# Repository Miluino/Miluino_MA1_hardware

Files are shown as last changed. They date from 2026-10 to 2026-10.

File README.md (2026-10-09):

# MDR32 Miluino

> [!IMPORTANT]
> AI-агенты перед анализом или изменением этого репозитория обязаны прочитать [общие правила работы AI-агентов](https://github.com/Miluino/dev-guidelines/blob/master/ai-agents.md), затем указанные ниже документы, относящиеся к текущей задаче. Полный рекурсивный анализ репозитория без необходимости не выполняется.

Проект новой ревизии отладочной платы на микроконтроллере `К1986ВЕ92FI`. Плата перерабатывается практически заново, поскольку исходная Miluino содержит конфликты выводов и другие схемотехнические ограничения.

Цель проекта — получить плату, которая:

- имеет геометрию разъёмов Arduino UNO и STMorpho; штатные шилды разрабатываются для Miluino, а совместимость готовых шилдов требует проверки распиновки, напряжений и направления питания пользователем;
- повторяет механическую карту STM32 Morpho платы `NUCLEO-F103RB`;
- предоставляет доступ к дополнительным функциям К1986ВЕ92FI через RAW-контакты;
- имеет однозначную коммутацию конфликтующих функций;
- содержит встроенный DAP-программатор/отладчик, VCP, USB и корректную систему питания.

## Техническая документация

Описание актуальной проектной схемы для технических специалистов разбито по узлам:

1. [Общее описание платы](docs/Техническая%20документация/01_Общее_описание_платы.md) — назначение, состав, интерфейсы и основные режимы.
2. [Питание платы и внешних устройств](docs/Техническая%20документация/02_Питание_и_внешние_выходы.md) — источники, T-селектор, защищённые выходы, токовые бюджеты и ограничения.
3. [К1986ВЕ92FI: распиновка и программирование](docs/Техническая%20документация/03_К1986_распиновка_и_программирование.md) — все выводы, Arduino, STMorpho, переключатели, USB-C и способы программирования.
4. [STM32F103CBU6: распиновка программатора](docs/Техническая%20документация/04_Программатор_распиновка.md) — все выводы, USB-C, отладочные разъёмы и служебные интерфейсы.

## С чего начать в новом чате

1. Прочитать этот README.
2. Для работы с выводами и текущим сигнальным листом обязательно перечитать [`docs/MDR32_MILUINO_pin_mapping.md`](docs/MDR32_MILUINO_pin_mapping.md).
3. Для работы с DAP прочитать релевантные разделы [`docs/CMSIS_DAP_rework.md`](docs/CMSIS_DAP_rework.md) и [`docs/CMSIS_DAP_power_reset_questions.md`](docs/CMSIS_DAP_power_reset_questions.md).
4. [`docs/Первоначальный промт.md`](docs/Первоначальный%20промт.md) использовать только как исторический контекст — повторно выполнять его не нужно.
5. Перед изменением любого рабочего документа перечитать его с диска: структура таблиц могла быть вручную изменена в ходе разработки.

При противоречии источников использовать следующий приоритет:

1. актуальная принципиальная схема;
2. `docs/MDR32_MILUINO_pin_mapping.md`;
3. этот README;
4. `docs/PROJECT_CONTEXT.md` и более ранние документы;
5. история обсуждений и первоначальный промт.

`docs/PROJECT_CONTEXT.md` содержит расширенный исторический контекст, но некоторые его формулировки о MODE, JTAG и AREF уже устарели.

## Текущая стадия

| Часть проекта | Оценочная готовность | Состояние |
|---|---:|---|
| Архитектура сигналов и распиновка | 85–90% | Основные назначения и конфликты проработаны |
| Сигнальный лист К1986ВЕ92FI | 80–85% | Реализован, требуется завершить номиналы и служебную обвязку |
| Полная электрическая схема | 45–55% | Не завершены питание, DAP, USB и итоговая проверка |

Распределение ограниченного количества выводов в основном закончено. Проект пока не готов к окончательной разводке PCB: сначала необходимо спроектировать питание и заземление, затем закончить DAP и остальные интерфейсные листы.

## Зафиксированные решения сигнального листа

### Arduino и Morpho

- Опорная карта STMorpho — `NUCLEO-F103RB`, Figure 12 на странице 28 UM1724.
- Обозначения Arduino I2C: `D18/SDA` и `D19/SCL`.
- Единственная аппаратная шина I2C К1986 использует `PC1/SDA1` и `PC0/SCL1`.
- D18/D19 постоянно подключены к PC1/PC0; A4/A5 переключаются между ADC и дублированием этой I2C-шины.
- `IOREF=3,3 В`. Наличие +5 В на Arduino-разъёме не означает 5-вольтовые логические уровни GPIO.
- `BOOT0` Nucleo оставлен NC.
- `MODE[2:0]` полностью изолированы от Morpho, BOOT0 и внешних GPIO и задаются только локальными переключателями.

### UART, VCP и отладка

- Arduino D1/D0 постоянно подключены к `PB5/UART1_TXD` и `PB6/UART1_RXD`.
- VCP использует UART2 на PD0/PD1 через нормально не установленные R1105/R1106.
- В штатном состоянии PD0/PD1 подключены к Morpho и JTAG_B через R1005/R1006.
- JTAG реализован групповым джамперным `JTAG_Channel_Selector` на пять сигналов: общая JTAG-шина выбирает JTAG_A на PB0–PB4 либо JTAG_B на PD0–PD4.
- Одновременное соединение одного JTAG-сигнала с каналами A и B запрещено.
- XP7 используется для SWD внешней target с логическими уровнями 3,3 В; его контакт 1 называется `EXT_VTREF` и принимает опорное напряжение от внешней платы.
- Питание внешней target через XP7 не передаётся. Для намеренной подачи питания от программатора предусматриваются отдельные контакты `+5V_DAP_OUT` и `+3V3_DAP_OUT`; общий контакт GND берётся с расположенного рядом `SPARE JMP`. Оба выхода используют общий токовый ключ `TPS2553-1` с целевым суммарным пределом около 300 мА.
- Встроенный DAP реализует только SWD: PB13 формирует SWCLK, PB14 используется как единая двунаправленная линия SWDIO, а PB12 управляет внешним NMOS линии nRESET.
- nRESET встроенного DAP формируется внешним NMOS 2N7002; PB12 подключён к gate через 1 кОм, gate подтянут к GND резистором 10 кОм.
- Выбранный XP8 сигнал VTref контролируется NMOS-детектором с активным низким выходом `nDAP_VTREF_PRESENT` на PA0: в gate включён последовательный резистор 1 кОм, gate подтянут к source резистором 10 кОм, drain подтянут к `+3V3_DAP` резистором 10 кОм.
- Детектор VTref подтверждает только наличие напряжения и не является проверкой диапазона 3,0...3,6 В; подключать разрешается только target с логикой 3,3 В.
- Логгер DAP использует PA9/USART1_TX как `DAP_LOG_TX` и PA10/USART1_RX как `DAP_LOG_RX`.
- Первичная прошивка, восстановление и отладка STM32F103 выполняются внешним SWD-адаптером через установленный XP5 1x5 с шагом 2,54 мм: `+3V3_DAP`, SWDIO, GND, SWCLK и NRST. Контакт `+3V3_DAP` используется как VTref, а не как вход питания.
- XP5 UART и XP9 BOOT0 удаляются; BOOT0 и PB2/BOOT1 постоянно подтягиваются к GND через 10 кОм. Отдельная кнопка RESET DAP не устанавливается, перезапуск и смена прошивки выполняются с полным отключением питания всей платы.
- Локальная линия `TARGET_nRESET` имеет единственную подтяжку к `+3V3_TGT`; кнопка, встроенный DAP, внешний DAP и shield могут только притягивать её к GND. Активный высокий уровень и подтяжка к 5 В не предусматриваются; C1 номиналом 100 нФ, X7R устанавливается между `TARGET_nRESET` и GND для фильтрации помех и дребезга кнопки.

### Тактирование и служебные сигналы

- Штатный HSE: `DAP_MCO -> R109 22 Ом -> DAP_MCO_Line -> R1003 0 Ом -> OSC_IN`; отдельный `R_EN_DAP` не устанавливается.
- Локальный кварц HSE подключается через R1103/R1213, внешний генератор через R1203; сервисный OSC_OUT выведен через R1113.
- PE6/PE7 штатно выведены на Morpho через R1007/R1008; локальный LSE выбирается через R1107/R1108.
- WAKEUP имеет постоянную подтяжку к VCC и подключается к Morpho через нормально не установленный R13. Внешнее устройство должно использовать open-drain или open-collector.
- STANDBY выводится на Morpho через последовательный резистор и используется внешней платой только как входной сигнал.
- Пользовательская кнопка использует PB9 и отключается от него резистором R9.
- Четыре active-high LED используют PA1, PA2, PA3 и PA5 через индивидуальные токоограничивающие резисторы.

### USB целевого К1986

- Контроллер `MDR_USB` поддерживает программно выбираемые режимы Device и Host по USB 1.0, скорости Full Speed 12 Мбит/с и Low Speed 1,5 Мбит/с.
- Возможность Host/Device внутри К1986 не делает разъём автоматически двухролевым USB-C: выводов CC и встроенного управления VBUS у МК нет.
- USB-C target работает только как постоянный Device/UFP/Sink: CC1 и CC2 имеют отдельные `Rd=5,1 кОм, 1 %` к GND, а VBUS используется только как вход питания. Режимы Host/DFP/Source и dual-role через этот разъём не поддерживаются.
- VBUS USB-C target поступает непосредственно на свой вход T-селектора: дополнительный eFuse или ограничитель тока в этой ветви не устанавливается. Потребление через этот разъём должно соответствовать разрешённому USB-хостом току; заявление тока в дескрипторе DAP относится к другому USB-C. Экраны обоих USB-C соединены с GND напрямую.
- Для DP/DN в любом варианте нужны низкоёмкостная ESD-защита, места под последовательные согласующие резисторы и корректная дифференциальная трассировка.
- Следует учесть errata 0033: при наличии Ucc и отсутствии внутреннего питания USB, в том числе до его запуска и в STANDBY, на DP и DN могут одновременно включаться внутренние подтяжки 1,5 кОм к Ucc.

### Питание target от VIN

- Для входа VIN принят рабочий диапазон 8...18 В с целевым номиналом 12 В.
- Стабильные `+5V_IN_Line` формирует синхронный преобразователь `LMR51410XDBVR`, работающий на частоте 400 кГц в режиме PFM. Приняты дроссель 33 мкГн, входные конденсаторы 4,7 мкФ + 100 нФ, bootstrap-конденсатор 100 нФ, выходной конденсатор 22 мкФ и делитель обратной связи 118 кОм / 22,1 кОм.
- Вывод EN `LMR51410XDBVR` подключается непосредственно к VIN. Внешний диод Шоттки, дополнительный bulk-конденсатор и резисторы минимальной нагрузки не устанавливаются; полезная нагрузка target ограничена принятыми 300 мА.
- Общий выход T-селектора называется `+5V_TGT`; от него `TLV76133DCYR` с входным конденсатором 1 мкФ X7R и выходным 4,7 мкФ X7R формирует `+3V3_TGT` для К1986 и IOREF.
- От `+5V_TGT` второй `TPS2553-1` питает защищённую ветвь Output Power для внешнего питания: `+5V_Out_Line` идёт на контакт +5V, а отдельный `TLV76133DCYR` после ключа формирует `+3V3_Out_Line` для контакта +3V3. Эти же защищённые шины выведены на STMorpho CN7.11/CN7.18 (+5V) и CN7.9/CN7.16 (+3V3); ток нагрузок Arduino и этих контактов Morpho учитывается в одном пределе второго TPS2553-1; R28=100 кОм; типовой порог ограничения около 266 мА, расчётный верхний порог при допуске резистора 1 % около 306 мА. Входом `EN` управляет только PB10 К1986 через штатно установленный R1004=0 Ом и сеть `TGT_OUTPUT_PWR_EN` при любом выбранном источнике target; R27=10 кОм удерживает `EN` на GND до настройки GPIO. Прошивка не включает защищённые выходы автоматически после инициализации: PB10 переводится в активное состояние только по явной команде. Ветвь к Morpho CN10.2 через R1104=0 Ом штатно разомкнута. `DAP_TARGET_PWR_EN` к этому ключу не подключается.
- Прямые контакты STMorpho CN7.5/CN7.12/CN7.33 (`+3V3_TGT`) и CN7.6/CN7.26/CN10.8 (`+5V_TGT`) допускаются только для высокоомного контроля напряжения при необходимости. Питать от них шилд или другую внешнюю нагрузку и подавать через них внешнее напряжение строго запрещено. IOREF на CN7.12 показывает уровень питания К1986 независимо от состояния PB10; CN7.26 позволяет контролировать `+5V_TGT` при выключенных защищённых выходах. Ограничение тока и запрет обратной подачи на прямых контактах не обеспечены аппаратно.
- При питании К1986 от USB-C DAP для расчёта бюджета VBUS зарезервировано по 100 мА для К1986 и STM32F103 с запасом относительно данных производителей. Суммарный ток внешних нагрузок выходов DAP и защищённой ветви Output Power (Arduino/Morpho) ограничен правилом эксплуатации 300 мА: 100 + 100 + 300 = 500 мА, заявленные для USB-C DAP. Любая нагрузка на прямых контактах Morpho тоже входит в этот внешний бюджет 300 мА, хотя второй TPS2553-1 её не ограничивает. Два TPS2553-1 ограничивают ток каждый в своей ветви и аппаратно не обеспечивают общий предел 300 мА; постоянная значительная нагрузка сразу на оба канала не является штатным сценарием. При питании К1986 от USB-C target или VIN бюджеты источников рассчитываются отдельно.
- `FAULT` ключа ветви Output Power имеет локальную светодиодную индикацию и подтяжку R26=100 кОм к `+5V_TGT`. Для опционального чтения К1986 сигнал подан на gate VT1=2N7002; source соединён с GND, drain подтянут R24=10 кОм к `+3V3_TGT` и через R25=1 кОм соединяется с PE3/CN10.10. R25 штатно не установлен (DNP), поэтому по умолчанию PE3 остаётся свободным GPIO. При установленном R25 высокий уровень PE3 означает аварию, низкий — отсутствие активного `FAULT`, но не подтверждает наличие выходного напряжения. Контакт CN10.10 в этой конфигурации нельзя использовать как независимый вход или выход шилда. `FAULT` ключа DAP остаётся только на локальном светодиоде и не подаётся на STM32F103 или К1986. Версия ключа `-1` защёлкивается при аварии; повторное включение требует переключения `EN` либо снятия питания. Автоматическое программное восстановление не предусматривается.
- Отдельный eFuse ветви VIN не устанавливается. Короткое замыкание на открытых контактах питания или во внешней проводке считается маловероятным принятым риском; встроенные ограничение тока и hiccup-защита `LMR51410XDBVR` являются только аварийной самозащитой микросхемы.
- Штатное питание платы осуществляется через USB-C DAP. Вход VIN не имеет отдельной защиты от переполюсовки, длительного перенапряжения и броска входного тока; внешний источник либо shield должен обеспечивать правильную полярность, стабилизированное напряжение 8...18 В, ограничение тока и необходимую входную защиту.

### AREF

Штатный R1009 соединяет Arduino AREF с `+3V3_TGT`; R1109 к `PD0/JB_TMS_Line` штатно не устанавливается. Внешняя опора АЦП через AREF в текущей сборке не поддерживается: для неё согласована цепь AREF → R1109 → `PD0/JB_TMS_Line` → R1005 → `ADC0_REF+` и уже предусмотренный в схеме R1206=0 Ом (DNP) от `ADC1_REF−` к GND; при внешней опоре Morpho CN10.34 должен оставаться свободным, JTAG_B — отключённым. Питание AUcc и связь AGND с GND проверяются по листу питания; подавать внешнее напряжение на AREF при установленном R1009 нельзя.

## Правило аннотации резисторов-перемычек

В Comment компонентов `.IntLib` записывается только номинал с множителем и десятичной запятой (например, `4,7u`, `22,1k`, `0`) либо модель; единицы, допуски, роль компонента и DNP указываются в Description. Для неутверждённого номинала или модели используется `TBD`. Description заполнен на трёх листах, включая символы `.SchLib`; их Comment и Designator требуют отдельной аннотации.

Для Designator R, C, HL и VT диапазон 1…99 отведён узлам К1986, 100…199 — узлам DAP. Порядок назначения следует листам 1–3 PDF; внутри листа элементы нумеруются сверху вниз по столбцам, затем слева направо. Одиночные резисторы, включая DNP, входят в диапазон своего узла.

- R1000…R1099 — штатные, нормально установленные резисторы;
- R1100…R1199 — первый альтернативный, нормально не установленный канал;
- R1200…R1299 — второй альтернативный, нормально не установленный канал;
- элементы с одинаковыми двумя последними цифрами образуют группу выбора;
- для двух штатно не установленных ветвей OSC_OUT используется пара R1113/R1213 без позиции R1013;
- в группе одновременно устанавливается только один канал;
- JTAG_A/JTAG_B выбирается джамперами и в эту систему резисторов не входит.
- Штатная комплектация и DNP-элементы пока задаются Description компонентов и таблицей конфигураций; отдельный вариант сборки Altium не создан. Перед выпуском ведомости комплектации DNP-позиции требуется отфильтровать вручную либо оформить вариант сборки.

Полная фактическая таблица R1000–R1213 и типовые конфигурации находятся в разделе 13 [`MDR32_MILUINO_pin_mapping.md`](docs/MDR32_MILUINO_pin_mapping.md).

## Что ещё предстоит спроектировать

- завершить проверку заземления и распределения Ucc/AUcc/AUcc1; BUcc штатно напрямую подключён к `+3V3_TGT`, отдельный резервный источник не предусматривается;
- подтвердить измерениями диапазон ограничения второго TPS2553-1 при R28=100 кОм; определить команду включения `TGT_OUTPUT_PWR_EN` в прошивке К1986 и проверить её поведение при разных источниках питания, сбросе и перегрузке. Автоматическое включение после инициализации не предусматривается;
- проверить для будущего режима внешней опоры уже предусмотренную цепь R1109+R1005/R1206 и допустимый диапазон опоры;
- локальную развязку всех выводов питания;
- окончательный номинал подтяжки `TARGET_nRESET`, ESD-защиту линии и необходимость внешнего супервизора питания target;
- выбрать конкретные диоды Шоттки защиты LDO `+3V3_DAP_OUT` и проверить ресурсы прошивки CMSIS-DAP v2 + CDC/VCP + SWO;
- подтвердить измерениями общий токовый предел, защиту от КЗ и обратного питания выходов `+5V_DAP_OUT` и `+3V3_DAP_OUT`;
- завершить номиналы и согласующие элементы USB-C целевого К1986 в принятой конфигурации Device/UFP/Sink; отдельная силовая защита VBUS не устанавливается;
- окончательные номиналы MODE, RESET, LED, кнопки, WAKEUP/STANDBY и кварцев;
- защиту внешних аналоговых и цифровых линий;
- завершить Comment/Designator символов `.SchLib`, утвердить оставленные `TBD` номиналы и исполнения, затем выполнить ERC, проверку нетлиста, BOM и посадочных мест.

## Документы проекта

| Файл | Назначение |
|---|---|
| [`docs/MDR32_MILUINO_pin_mapping.md`](docs/MDR32_MILUINO_pin_mapping.md) | Главная актуальная карта выводов, разъёмов и резисторов выбора |
| [`docs/CMSIS_DAP_rework.md`](docs/CMSIS_DAP_rework.md) | Архитектура встроенного CMSIS-DAP; часть решений ещё требует утверждения |
| [`docs/CMSIS_DAP_power_reset_questions.md`](docs/CMSIS_DAP_power_reset_questions.md) | Вопросы и критерии проверки питания, VTref и RESET |
| [`docs/STM32F103_DAP_pinout.md`](docs/STM32F103_DAP_pinout.md) | Распиновка DD2 и рекомендуемые подключения встроенного DAP |
| [`docs/future_changes.md`](docs/future_changes.md) | Согласованные изменения, ещё не внесённые в принципиальную схему |
| [`docs/PROJECT_CONTEXT.md`](docs/PROJECT_CONTEXT.md) | Расширенный, но частично устаревший контекст предыдущих обсуждений |
| [`docs/Первоначальный промт.md`](docs/Первоначальный%20промт.md) | Историческая постановка задачи, не инструкция к повторному выполнению |
| [`codex/datasheet_K1986VE92FI_pinout.md`](codex/datasheet_K1986VE92FI_pinout.md) | Индекс выводов и функций К1986ВЕ92FI |
| [`codex/datasheet_STM32_Nucleo64_UM1724.md`](codex/datasheet_STM32_Nucleo64_UM1724.md) | Индекс руководства Nucleo-64 |
| [`codex/datasheet_Arduino_UNO_R4_Minima.md`](codex/datasheet_Arduino_UNO_R4_Minima.md) | Индекс Arduino UNO R4 Minima |

Каталог `datasheets` содержит первичные PDF/DOCX. Файлы в `codex` являются только поисковыми индексами; критичные электрические параметры необходимо проверять по оригинальным документам.

## Ключевые ограничения

- GPIO платы работают с логическими уровнями 3,3 В; полная совместимость с произвольными 5-вольтовыми shields не заявляется.
- PD0–PD7 нельзя считать 5-вольт-совместимыми.
- Два активных выхода нельзя объединять одной дорожкой.
- RAW-контакт — дополнительная точка той же сети, а не независимый сигнал.
- Альтернативные резисторные каналы переключаются только на обесточенной плате.
- MODE считывается при включении питания; обычный RESET не применяет новое состояние MODE.
- Оба USB-C работают только как Device/UFP/Sink и имеют отдельные `Rd=5,1 кОм, 1 %` на CC1 и CC2; режимы Host/Source и dual-role через эти разъёмы не поддерживаются.
- В общей силовой части и цепи RESET локальной target остаются открытые вопросы; для будущей внешней опоры AREF согласована коммутация R1005/R1109/R1206; R1206 уже внесён в схему как DNP, а параметры режима требуют проверки. Согласованные аппаратные узлы встроенного DAP зафиксированы в профильных документах.
- `EXT_VTREF` является входом контроля питания внешней target и не должен использоваться как выход питания; для этого предназначены только отдельные контакты `+5V_DAP_OUT` и `+3V3_DAP_OUT`, а GND берётся с расположенного рядом `SPARE JMP`.

## Рекомендуемое первое сообщение в новом чате

```text
Прочитай README.md и актуальные рабочие документы, на которые он ссылается.
Первоначальный промт повторно не выполняй. Используй текущую принципиальную
схему и MDR32_MILUINO_pin_mapping.md как основные источники состояния проекта.
После этого продолжим обсуждение переработки Miluino с текущей стадии.
```

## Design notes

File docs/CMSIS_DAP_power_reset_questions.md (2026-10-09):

# Питание, VTref и RESET для CMSIS-DAP

## 1. Назначение и статус документа

Документ фиксирует согласованные решения по питанию, VTref и RESET новой ревизии MDR32 MILUINO, а также вопросы, которые необходимо закрыть до утверждения принципиальной схемы. Он заменяет исходный чек-лист: принятые решения изложены связно, а неутверждённые параметры перечислены отдельно.

Связанный документ: [CMSIS_DAP_rework.md](CMSIS_DAP_rework.md).

## 2. Неизменяемые исходные решения

Для текущей ревизии приняты следующие ограничения:

1. Встроенный DAP остаётся на STM32F103 и получает собственное питание от USB-C DAP.
2. DAP и локальный К1986ВЕ92FI рассматриваются как отдельные домены `+3V3_DAP` и `+3V3_TGT` с общей GND; гальваническая изоляция не предусматривается.
3. XP8/DAP_ROUTE одновременно переключает SWCLK, SWDIO, nRESET, VTref и SWO между `EXTERNAL / OFF / TARGET`.
4. XP7 не питает внешнюю target. Его контакт 1 `EXT_VTREF` используется только как вход опорного напряжения.
5. ARM Cortex Debug 10-pin подключён к локальной общей DBG-шине и получает VTref от локальной target.
6. nRESET локальной и внешней target не соединяются постоянно.
7. RESET встроенного STM32F103 и nRESET target являются разными цепями.
8. После изменения MODE[2:0] требуется полный цикл выключения и включения основного питания К1986ВЕ92FI; обычного RESET недостаточно.
9. Оба USB-разъёма новой ревизии выполняются в формате USB-C.
10. Встроенный DAP поддерживает только target с логическими уровнями 3,3 В; поддержка target с уровнями 1,8 В или 2,5 В не предусматривается.
11. Специальная аппаратная защита от подпитки выключенного домена через сигнальные линии не предусматривается. Связанный с этим риск принимается и относится к ограничениям эксплуатации платы.
12. Возможность питания внешней target от программатора сохраняется только через отдельные контакты `+5V_DAP_OUT` и `+3V3_DAP_OUT`, не связанные с силовой передачей через XP7; GND берётся с расположенного рядом `SPARE JMP`.
13. Встроенный DAP реализует только SWD: PB13 используется как SWCLK, PB14 — как единая двунаправленная линия SWDIO, PB12 управляет внешним NMOS линии nRESET.
14. Контроль наличия выбранного VTref выполняется согласованным NMOS-детектором с активным низким выходом; компаратор не устанавливается.
15. Ветвь управления nRESET target от встроенного DAP формируется внешним NMOS 2N7002 по схеме открытого стока; подтяжка остаётся на target-стороне.
16. STM32F103 программируется, восстанавливается и отлаживается внешним SWD-адаптером через установленный разъём XP5 1x5 с шагом 2,54 мм; XP5 UART и XP9 BOOT0 не используются.
17. Отдельная кнопка RESET DAP не устанавливается; его обычная перезагрузка и смена прошивки предусматривают полное отключение питания всей отладочной платы.
18. Между `TARGET_nRESET` и GND устанавливается C1 номиналом 100 нФ, X7R для фильтрации помех и дребезга кнопки.
19. Оба внешних выхода питания DAP образуют единый защищённый домен с общим ограничением тока; отдельные независимые токовые бюджеты для них не предусматриваются.
20. Специальная защита от обратного питания устанавливается только на пользовательских выходах `+5V_DAP_OUT` и `+3V3_DAP_OUT`. Остальные шины не предназначены для подачи внешнего напряжения и дополнительных обратных ключей не получают.

## 3. Согласованная архитектура питания

### 3.1. Источники и преобразование

Домен DAP питается только от собственного USB-C:

```text
USB_DAP_VBUS --+--> TLV76133DCYR --> +3V3_DAP
               |
               +--> TPS2553-1 --> +5V_DAP_OUT
               |                      |
               |                      +--> D1 Шоттки --> TLV76133DCYR --> +3V3_DAP_OUT
               |                                           ^              |
               |                                           +-- D2 Шоттки -+
               |
               +--> P-MOSFET --> +5V_DAP_USB --> DAP-вход T-селектора --> +5V_TGT --> +3V3_TGT --> К1986
```

Входом всех трёх трактов является номинальный VBUS 5 В USB-C DAP. Поддержка USB Power Delivery и подача на VBUS напряжений 9...20 В не предусматриваются. Внутренний домен `+3V3_DAP` не нагружается питанием внешней платы: отдельный LDO внешнего выхода получает питание от защищённой пятивольтовой ветви после `TPS2553-1`.

`TPS2553-1` задаёт общий токовый предел двух внешних выходов и отключает N-канальный силовой MOSFET при обратном напряжении. Для `R122=100 кОм, 1 %` типовой порог составляет около 266 мА; расчёт по формулам TI с учётом допуска резистора даёт ориентировочно 232...306 мА. Поэтому 300 мА — целевой уровень, а не гарантированный максимальный порог или гарантированно доступный ток нагрузки. При `VOUT > VIN` защита имеет конечное время срабатывания: порог компаратора составляет 95...190 мВ, отключение MOSFET занимает 3...7 мс, после чего версия `-1` остаётся защёлкнутой до переключения `EN` либо полного снятия питания. Поэтому узел блокирует продолжительное обратное питание USB VBUS, но не считается безынерционным ideal-diode.

На входе `TPS2553-1` устанавливается неполярный керамический конденсатор 1 мкФ, X7R, не менее 10 В. На выходе устанавливается неполярный керамический конденсатор 22 мкФ, X7R, не менее 10 В; его эффективная ёмкость при постоянном смещении 5 В должна быть не менее 10 мкФ. Предпочтителен корпус 1206 или крупнее либо параллельное включение двух конденсаторов 10 мкФ после проверки зависимости ёмкости от напряжения. Этот конденсатор служит накопительной ёмкостью для переходных процессов внешней нагрузки; полярный символ применяется только при фактическом выборе электролитического, танталового или полимерного компонента.

PA1 STM32F103 формирует активный высоким уровнем сигнал `DAP_TARGET_PWR_EN`. Сигнал напрямую подключается к `EN` микросхемы `TPS2553-1` внешних выходов и через резистор 1 кОм управляет gate отдельного NMOS 2N7002. Source 2N7002 соединяется с GND, а drain — с gate силового P-MOSFET ветви питания локальной target. Source P-MOSFET подключается к `USB_DAP_VBUS`, drain формирует `+5V_DAP_USB`, а gate подтягивается к source резистором 10 кОм. При `DAP_TARGET_PWR_EN=1` включаются оба независимых силовых тракта; при нуле или high-Z они выключены. Ток К1986 не проходит через `TPS2553-1` внешних выходов, поэтому авария этого ключа не должна выключать локальную target.

У gate NMOS установлен резистор 10 кОм к GND; PA1 подключён к gate через последовательный резистор 1 кОм. Поэтому PA1 и вход `EN` TPS2553-1 внешних выходов получают путь к GND через 1 кОм + 10 кОм, а отдельной прямой подтяжки 10 кОм на общей сети `DAP_TARGET_PWR_EN` в текущей схеме нет. После сброса PA1 остаётся высокоимпедансным входом, и эта цепь удерживает оба тракта выключенными. Прошивка сначала записывает ноль в выходной регистр PA1 и переводит его в push-pull output, а единицу устанавливает только после получения `SET_CONFIGURATION` для конфигурации USB с заявленным током 500 мА. При USB suspend, сбросе или деконфигурации шины, `SET_CONFIGURATION(0)` и потере VBUS сигнал должен быть сброшен в ноль. Выход `FAULT` этого ключа не подключён к STM32F103; программное обнаружение аварии и автоматические попытки повторного включения не предусматриваются.

Для питания локальной target предусмотрены три источника:

1. коммутируемый сигналом `DAP_TARGET_PWR_EN` VBUS USB-C DAP;
2. необработанный `USB_VBUS` отдельного USB-C target без дополнительного ограничителя тока на плате;
3. внешний источник, подключённый к VIN на Arduino/STMorpho.

Ветвь VIN перед селектором содержит `LMR51410XDBVR`, формирующий стабильные 5 В из входных 8...18 В. USB-C target подаёт свой VBUS на селектор без отдельного eFuse; допустимое потребление определяется USB-хостом и конфигурацией именно этого USB-устройства. Структура target имеет вид:

```text
USB-C DAP VBUS -- P-MOSFET ------------------+
                                              |
USB-C target USB_VBUS ------------------------+-- T-селектор -- +5V_TGT -- TLV76133DCYR -- +3V3_TGT -- К1986, IOREF, Morpho CN7.5/CN7.12/CN7.33
                                              |                    |
VIN ---------------- LMR51410XDBVR -----------+                    +-- Morpho CN7.6/CN7.26/CN10.8 (+5V; CN7.26 — контроль)
                                                                   |
                                                                   +-- второй TPS2553-1 -- +5V_Out_Line -- Arduino +5V, Morpho CN7.11/CN7.18
                                                                                         |
                                                                                         +-- TLV76133DCYR -- +3V3_Out_Line -- Arduino +3V3, Morpho CN7.9/CN7.16
```

Рабочие имена сетей для последующего согласования схемы:

- `USB_DAP_VBUS` и `USB_VBUS` — VBUS отдельных USB-C DAP и target;
- `+5V_DAP_USB` — коммутируемая P-MOSFET ветвь от `USB_DAP_VBUS`, разрешаемая сигналом `DAP_TARGET_PWR_EN`; `USB_VBUS` идёт от USB-C target на селектор напрямую;
- `+5V_IN_Line` — выход `LMR51410XDBVR` до T-селектора;
- `+5V_TGT` — общий выход T-селектора;
- `+3V3_TGT` — выход `TLV76133DCYR` локальной target;
- `+5V_Out_Line` и `+3V3_Out_Line` — выходы ветви Output Power после второго TPS2553-1, причём 3,3 В формируются отдельным LDO;
- `TGT_OUTPUT_PWR_EN` — активный высоким уровнем сигнал PB10 К1986 на `EN` второго TPS2553-1 ветви Output Power; при сбросе удерживается на GND резистором R27=10 кОм;
- `+3V3_DAP` — отдельное питание STM32F103;
- `+5V_DAP_OUT` — защищённая пятивольтовая ветвь внешнего питания после `TPS2553-1`;
- `+3V3_DAP_OUT` — выход отдельного LDO внешнего питания после `TPS2553-1`.

### 3.2. T-образный селектор источника

Источник target выбирается вручную одним стандартным джампером 2,54 мм на четырёхконтактной T-образной гребёнке. Центральный контакт подключён к `+5V_TGT`, три окружающих контакта — к `+5V_DAP_USB`, `USB_VBUS` и `+5V_IN_Line`.

Правила эксплуатации:

- устанавливается только один джампер;
- автоматический приоритет источников отсутствует;
- без джампера `+5V_TGT` отключена от всех источников и локальная target выключена;
- несколько физических источников разрешено подключать одновременно, поскольку к target подключается только выбранная ветвь;
- невыбранные ветви могут оставаться под напряжением, но должны быть отключены от нагрузки;
- механическое разделение контактов селектора исключает прямое объединение источников; отдельной силовой защиты `USB_VBUS` на плате нет.

Рабочее описание посадочного места: `T-shaped selector for choosing the target MCU power source`.

### 3.3. Назначение силовых контактов Arduino и STMorpho

Контакты `+5V` и `+3V3` являются только выходами питания платы. Они не входят в перечень допустимых внешних источников и не должны использоваться для подачи питания на Miluino.

На Arduino выходы питаются от общего второго TPS2553-1: `+5V_Out_Line` непосредственно после ключа, `+3V3_Out_Line` после отдельного LDO. Их токи учитываются в одном пределе ключа; R28=100 кОм задаёт типовой порог около 266 мА и расчётную верхнюю границу около 306 мА при допуске резистора 1 %. К защищённым шинам подключены Morpho CN7.11/CN7.18 (+5V) и CN7.9/CN7.16 (+3V3); их нагрузки входят в общий предел с выходами Arduino. Прямые контакты CN7.6/CN7.26/CN10.8 (`+5V_TGT`) и CN7.5/CN7.12/CN7.33 (`+3V3_TGT`) предназначены исключительно для высокоомного контроля напряжения при необходимости: питание от них шилда или другой внешней нагрузки и внешняя подача напряжения через них строго запрещены. CN7.26 показывает `+5V_TGT` при выключенном втором TPS2553-1, а IOREF на CN7.12 показывает питание К1986 независимо от PB10. Это правило эксплуатации: ток прямых контактов и обратная подача не ограничены аппаратно.

При питании локального К1986 от USB-C DAP в бюджете `USB_DAP_VBUS` зарезервировано по 100 мА для К1986 и STM32F103 с запасом относительно данных производителей. На все внешние нагрузки выходов DAP и защищённой ветви Output Power (Arduino/Morpho) вместе отводится не более 300 мА: 100 + 100 + 300 = 500 мА, заявленные для USB-C DAP. Два TPS2553-1 ограничивают каждый свою ветвь и не обеспечивают общий предел 300 мА аппаратно; это ограничение необходимо соблюдать при эксплуатации. Постоянная значительная нагрузка одновременно на оба канала не является штатным сценарием. Любой ток с прямых контактов Morpho тоже входит в общий бюджет внешних нагрузок 300 мА, хотя второй TPS2553-1 его не ограничивает. При выборе USB-C target или VIN для питания К1986 токовые бюджеты источников считаются отдельно.

Вторым TPS2553-1 при любом положении силового T-селектора управляет только К1986: PB10, физический вывод 55, через штатно установленный R1004=0 Ом формирует `TGT_OUTPUT_PWR_EN` на `EN` ключа. R27=10 кОм подтягивает эту сеть к GND, сохраняя выходы выключенными до настройки PB10 и при сбросе К1986. Прошивка включает PB10 и защищённые выходы только по явной команде; автоматического включения после инициализации нет. Альтернативный R1104=0 Ом от PB10 к `PB10_Line` и Morpho CN10.2 штатно не установлен; одновременно устанавливать R1004 и R1104 нельзя. `DAP_TARGET_PWR_EN` электрически отделён от `TGT_OUTPUT_PWR_EN` и управляет только силовым P-MOSFET ветви DAP и первым TPS2553-1 внешних выходов DAP. Селектор выбирает источник `+5V_TGT` без коммутации управляющих сигналов.

`FAULT` первого TPS2553-1 внешних выходов DAP остаётся только в локальной цепи светодиодной индикации и не подключается к STM32F103 или К1986. `FAULT` второго TPS2553-1 ветви Output Power также управляет локальным светодиодом и подтянут R26=100 кОм к `+5V_TGT`. Для опционального чтения К1986 gate VT1=2N7002 подключён к этому узлу, source — к GND, drain через R24=10 кОм — к `+3V3_TGT`. R25=1 кОм соединяет drain с PE3/`PE3_Line` и Morpho CN10.10; R25 штатно не установлен (DNP). При его установке PE3 считывает высокий уровень при аварии и низкий при отпущенном `FAULT`; 5 В на PE3 не подаются, а CN10.10 нельзя одновременно использовать как независимый сигнал шилда. Низкий уровень PE3 не подтверждает наличие напряжения на выходе ключа. Оба ключа версии `-1` самостоятельно выключают свои выходы при аварии и остаются защёлкнутыми до переключения соответствующего `EN` либо полного снятия питания; автоматическое программное повторное включение не предусмотрено.

Единственным внешним входом, способным питать основной домен target помимо двух USB-C, является VIN. Контакты VIN Arduino и STMorpho относятся к одной входной сети и не являются двумя независимыми источниками.

Вывод BUcc К1986 напрямую подключён к `+3V3_TGT` и не считается четвёртым источником основного Ucc. Отдельный внешний резервный источник и блокировка обратного тока для BUcc не предусматриваются; через связанный контакт Morpho запрещено подавать питание на эту сеть.

Для собственных шилдов Miluino питание внешней нагрузки берётся только с защищённой ветви Output Power (Arduino/Morpho). Готовые шилды Nucleo или Arduino допускаются лишь после проверки пользователем распиновки, логических уровней, направления питания и нагрузки; совместимость и последствия подключения остаются ответственностью пользователя. Максимальный допустимый ток защищённых выходов должен быть указан в документации платы и проверен на прототипе.

### 3.4. Полное отключение и power cycle target

Снятие джампера T-селектора отключает силовые пути питания всего локального домена target, включая К1986 и модули, питаемые от его `+5V_TGT` и `+3V3_TGT`. Домен DAP при этом может оставаться включённым от USB-C DAP. Наличие электрически подключённых сигнальных линий означает, что снятие джампера само по себе не гарантирует абсолютное отсутствие остаточного напряжения на выключенном домене.

Между `+3V3_TGT` и GND на листе питания установлен постоянный параллельный разрядный резистор. Его окончательный номинал выбирается после определения суммарной ёмкости шины и проверки времени падения напряжения на прототипе; исходный ориентир — 4,7...10 кОм. Старое значение 118 кОм и описание резистора обратной связи у скопированного символа не считаются утверждённым номиналом этого узла.

В текущей ревизии не предусматриваются специальные буферы, ключи с `partial-power-down`/`Ioff` или иные аппаратные элементы, гарантированно исключающие подпитку выключенного target через SWD/JTAG, nRESET, SWO, UART, USB, Morpho, shield, `DAP_MCO` и защитные диоды GPIO. При включённом источнике сигнала и выключенном принимающем домене возможны остаточное напряжение, частичное питание и неопределённое состояние МК. Этот риск принимается; такие сочетания питания не считаются поддерживаемым режимом эксплуатации.

Отдельный активный разряд не требуется, если при штатной последовательности отключения параллельный резистор обеспечивает падение `+3V3_TGT` ниже порога повторного срабатывания POR за допустимое время. Окончательные порог и время выключения определяются по спецификации К1986 и результатам измерений. Перед применением нового MODE пользователь должен отключить активные внешние интерфейсы и источники сигналов, способные поддерживать остаточное питание target, и убедиться в полном выключении основного домена.

На плате предусматривается индикатор `TARGET_POWER_LED`, показывающий фактическое наличие `+3V3_TGT`. Он не заменяет измерение остаточного напряжения при проверке power cycle.

### 3.5. Работа target без включённого DAP

Питание target от USB-C target или VIN не гарантирует наличие тактового сигнала `DAP_MCO`, если DAP выключен. В автономной конфигурации прошивка должна использовать внутренний HSI либо пользователь должен установить предусмотренный локальный кварц или подать внешний тактовый сигнал. Выбор и правильная настройка автономного источника тактирования относятся к ответственности пользователя платы. Если `DAP_MCO` оставлен подключённым, сочетание `DAP ON / target OFF` относится к принятому риску междоменной подпитки.

### 3.6. Отдельное питание внешней target

Для внешней target предусматриваются отдельные контакты `+5V_DAP_OUT` и `+3V3_DAP_OUT` рядом с XP7. Отдельного GND в этом разъёме нет: общая земля берётся с расположенного рядом `SPARE JMP`. Питание не передаётся через контакт `EXT_VTREF`: этот контакт всегда остаётся входом от фактической шины VDD внешней платы.

При питании внешней платы от любого выхода DAP её фактическая шина логического питания 3,3 В должна быть отдельно соединена с `EXT_VTREF`, чтобы схема контроля видела действительное напряжение на target. Если используется `+5V_DAP_OUT`, внешняя плата самостоятельно формирует из него питание логики 3,3 В. Встроенный DAP не поддерживает target с логическими уровнями 5 В.

Оба выхода используют общий токовый ключ `TPS2553-1` и поэтому одновременно отключаются при защёлкивании защиты. Ток `+5V_DAP_OUT` и входной ток LDO ветви `+3V3_DAP_OUT` суммируются; заявлять полный токовый предел для каждого выхода одновременно запрещено. Одновременное подключение собственного источника внешней target к любому из этих выходов запрещено, если не предусмотрена специально рассчитанная развязка источников.

Ветвь `+3V3_DAP_OUT` выполняется на `TLV76133DCYR` с двумя внешними диодами Шоттки. D1 включается последовательно: анод к `+5V_DAP_OUT`, катод к локальной сети `DAP_OUT_LDO_IN` и входу LDO. D2 включается от выхода к входу LDO: анод к `+3V3_DAP_OUT`, катод к `DAP_OUT_LDO_IN`. D1 препятствует продолжительному обратному питанию `+5V_DAP_OUT`, а D2 ограничивает обратное напряжение на TLV761 и отводит ток в его входной конденсатор. Схема не является идеальной гальванической развязкой: при внешней подаче 3,3 В возможны кратковременный заряд входной ёмкости LDO и токи утечки, поэтому отсутствие опасного обратного тока необходимо подтвердить измерениями.

После D1 на `DAP_OUT_LDO_IN` устанавливается неполярный керамический входной конденсатор 1 мкФ, X7R, не менее 10 В. На `+3V3_DAP_OUT` устанавливается неполярный керамический выходной конденсатор 4,7 мкФ, X7R, не менее 6,3 В; для TLV761 его эффективная ёмкость должна быть не менее 0,47 мкФ, а ESR — находиться в допустимом диапазоне 2...500 мОм. Конкретные диоды Шоттки пока не выбраны; требуются малое прямое падение при токе до 300 мА, допустимый прямой ток не менее 0,5 А, предпочтительно 1 А, и `VRRM` не менее 10 В.

## 4. Силовая часть: принятые и открытые параметры

### 4.1. Диапазон VIN и преобразователь 5 В

Для ветви VIN принят синхронный понижающий преобразователь `LMR51410XDBVR` на 1 А с частотой 400 кГц и режимом PFM при малой нагрузке. Рабочий диапазон на входном разъёме составляет 8...18 В, целевое номинальное напряжение — 12 В.

Принята следующая обвязка `LMR51410XDBVR`:

- локальные входные конденсаторы 4,7 мкФ, 50 В, X7R и 100 нФ, 50 В, X7R непосредственно между VIN и GND; дополнительный bulk-конденсатор не устанавливается;
- дроссель 33 мкГн с допустимым среднеквадратичным током не менее 1,5 А, током насыщения не менее 2,5 А и малым DCR;
- bootstrap-конденсатор 100 нФ, 16 В, X7R между CB и SW;
- выходной конденсатор 22 мкФ, 16 В, X7R между `+5V_IN_Line` и GND;
- верхний резистор делителя обратной связи 118 кОм, 1 %, между `+5V_IN_Line` и FB и нижний резистор 22,1 кОм, 1 %, между FB и GND;
- прямое подключение EN к VIN без внешнего делителя UVLO;
- соединение GND с локальным полигоном, минимальная площадь импульсного контура VIN-SW-GND и удаление цепи FB от узла SW.

Внешний диод Шоттки и постоянная минимальная нагрузка для `LMR51410XDBVR` не требуются. Ранее рассмотренные два резистора `RC2512FK-0739RL` по 39 Ом не устанавливаются.

Максимальная полезная нагрузка target остаётся равной 300 мА. Номинальный ток `LMR51410XDBVR` 1 А обеспечивает запас для пуска и переходных процессов, но не увеличивает заявленный допустимый ток внешней нагрузки.

`XL1509E-5.0`, `LM2575S-5.0` и `LM2575HVR-5.0` рассмотрены, но не выбраны из-за более крупной обвязки; для `XL1509E-5.0` дополнительно требовалась постоянная минимальная нагрузка.

Штатное питание платы осуществляется через USB-C DAP. Вход VIN является дополнительным способом питания и не имеет на плате отдельной защиты от переполюсовки, длительного перенапряжения и броска входного тока. При подаче питания через VIN внешний источник или shield должен обеспечивать стабилизированное напряжение 8...18 В с номиналом 12 В, правильную полярность, ограничение тока и необходимую для условий эксплуатации входную защиту. Лабораторный источник 12 В допускается использовать при настроенном ограничении тока и предварительной проверке полярности.

### 4.2. Токовые бюджеты и защита источников

Остаётся определить или подтвердить измерениями:

- максимальный ток `+3V3_DAP`;
- распределение принятого полезного тока 300 мА между основными `+5V_TGT`/`+3V3_TGT` и выходами Arduino после второго TPS2553-1;
- допустимый ток каждой из трёх входных ветвей;
- подтверждение на прототипе гарантированного диапазона общего ограничения внешних выходов DAP при `RILIM=100 кОм, 1 %`;
- окончательные номиналы и исполнение светодиодов и их последовательных резисторов в локальных цепях индикации `FAULT`; при установке R25 — обработку входа PE3 прошивкой К1986 без автоматического повторного включения ключа;
- подтверждение на прототипе диапазона ограничения второго TPS2553-1 при R28=100 кОм и допустимого тока его выходов;
- допустимое падение напряжения и нагрев при максимальной нагрузке;
- поведение при перегрузке.

Для ветви VIN отдельный входной eFuse или точный ограничитель тока основного домена не устанавливается. Встроенные цикл-за-циклом ограничение тока и hiccup-защита `LMR51410XDBVR` считаются только аварийной самозащитой микросхемы и не задают допустимый ток target. Выходы Arduino +5V/+3V3 имеют общий второй TPS2553-1, а прямые контакты `+5V_TGT` и `+3V3_TGT` на STMorpho, включая контрольный CN7.26 и IOREF, отдельным ключом не защищены. Эксплуатация с замыканием либо внешняя подача питания на выходные контакты запрещены. При необходимости предохранитель, PTC и защита от переполюсовки или перенапряжения должны устанавливаться во внешнем источнике либо на shield.

### 4.3. Стабилизаторы и контроль питания

Для `+3V3_DAP`, `+3V3_DAP_OUT`, `+3V3_TGT` и `+3V3_Out_Line` принят `TLV76133DCYR` с фиксированным выходом 3,3 В в корпусе SOT-223. На входе каждого LDO устанавливается неполярный керамический конденсатор 1 мкФ, X7R, не менее 10 В; на выходе — 4,7 мкФ, X7R, не менее 6,3 В. Для выходной ёмкости допустим диапазон 1...220 мкФ при эффективном значении не менее 0,47 мкФ и ESR 2...500 мОм. Ветвь `+3V3_DAP_OUT` сохраняет описанную выше двухдиодную защиту. Для `+3V3_TGT` при токе 300 мА расчётное рассеивание составляет примерно 0,51 Вт при входе 5 В; тепловой режим, площадь меди и фактический запас по dropout необходимо проверить на прототипе.

Также остаются открытыми необходимость внешнего супервизора, использование power-good, пороги BOR/POR и набор контрольных точек. Минимально требуются точки измерения всех входных ветвей, `+5V_TGT`, `+3V3_TGT`, `+3V3_DAP`, `DBG_VTREF` и GND.

BUcc штатно напрямую подключён к `+3V3_TGT`; отдельный резервный источник и блокировка обратного тока в этот домен не предусматриваются.

## 5. VTref

Принята следующая топология:

- встроенный DAP поддерживает только target с логическими уровнями 3,3 В;
- в режиме `DAP_ROUTE=TARGET` источником `DBG_VTREF` является локальная `+3V3_TGT`;
- в режиме `DAP_ROUTE=EXTERNAL` сигнал `EXT_VTREF` приходит с XP7 от внешней target;
- в режиме `DAP_ROUTE=OFF` встроенный DAP физически отключён от VTref;
- XP7 никогда не выдаёт питание внешней target;
- ARM Cortex Debug 10-pin всегда видит локальный `DBG_VTREF` независимо от питания встроенного DAP.

Номинальное значение `EXT_VTREF` равно 3,3 В; рабочий ориентир для поддерживаемой внешней target — 3,0...3,6 В. VTref используется только для определения наличия допустимого питания target и не задаёт отдельное питание GPIO STM32F103. Преобразователи уровней для target с логикой 1,8 В или 2,5 В не устанавливаются.

Для контроля наличия VTref используется NMOS-детектор. Сигнал `DAP_VTREF` после XP8 через последовательный резистор 1 кОм подключается к gate NMOS; gate подтягивается к source резистором 10 кОм, source соединяется с GND, drain подключается к PA0 DD2 и подтягивается к `+3V3_DAP` резистором 10 кОм. При наличии VTref транзистор открыт и `nDAP_VTREF_PRESENT=0`, при отсутствии VTref транзистор закрыт и `nDAP_VTREF_PRESENT=1`. Для номинального VTref 3,3 В делитель 1 кОм/10 кОм формирует на gate около 3,0 В; конкретный NMOS должен быть выбран с гарантированной работой при таком напряжении gate.

Этот узел определяет только присутствие положительного напряжения и не имеет гарантированного порога 3,0 В. Он может распознать питание 1,8 В или 2,5 В как присутствующее, поэтому не является защитой от target с несовместимыми логическими уровнями. Компаратор не устанавливается; поддержка ограничена target с номинальным VTref 3,3 В эксплуатационным требованием.

До утверждения схемы необходимо выбрать конкретный NMOS и ESD-защиту входа `DAP_VTREF`, определить реакцию прошивки на отсутствующий или нестабильный VTref и предусмотреть контрольную точку `DAP_VTREF`. При `nDAP_VTREF_PRESENT=1` SWCLK и SWDIO должны оставаться high-Z, nRESET должен быть отпущен, а захват SWO — отключён.

## 6. Принятый риск междоменной подпитки

Специальная аппаратная защита от подпитки между доменами `+3V3_DAP` и `+3V3_TGT` через SWCLK, SWDIO, SWO, TDI, TDO, TMS, nRESET, VCP, `DAP_MCO` или внешний USB-UART не предусматривается. Последовательные резисторы могут ограничивать ток и улучшать целостность сигналов, но не считаются гарантированной блокировкой подпитки.

Поддерживаемый режим предполагает, что соединённые сигнальными линиями DAP и target одновременно имеют штатное питание 3,3 В. Работа при включённом передающем и выключенном принимающем домене не гарантируется. Возможные последствия — остаточное напряжение на выключенной шине, частичное питание МК, нарушение полного power cycle и неопределённое состояние выводов.

Перед отключением одного из доменов пользователь должен разорвать соответствующие маршруты `DAP_ROUTE`, VCP и внешнего UART, а при необходимости отключить `DAP_MCO` снятием R1003 номиналом 0 Ом и выключить формирование MCO на PA8. Соблюдение этой последовательности относится к ответственности пользователя платы.

Контакт `+3V3_TGT` сервисного UART-разъёма остаётся выходом опорного напряжения, а не входом питания.

## 7. Сброс target и DAP

### 7.1. nRESET target

Зафиксированы следующие требования:

- nRESET локальной target имеет подтяжку к `+3V3_TGT` на target-стороне;
- кнопка RESET, встроенный DAP, внешний DAP и shield могут только притягивать линию к GND по схеме open-drain/open-collector;
- ни один участник не должен активно формировать высокий уровень;
- подача на `TARGET_nRESET` напряжения 5 В и внешняя подтяжка к 5 В запрещены;
- между `TARGET_nRESET` и GND возле К1986 устанавливается C1 номиналом 100 нФ, X7R; он фильтрует короткие помехи и дребезг кнопки, а совместно с подтяжкой определяет длительность отпускания сброса;
- XP8 физически переключает nRESET между внешней target, OFF и локальной DBG-шиной;
- `DAP_ROUTE=OFF` отключает nRESET встроенного DAP;
- RESET DAP и nRESET target остаются независимыми;
- должны поддерживаться обычный аппаратный reset, длительное удержание и connect-under-reset;
- RESET не заменяет power cycle после изменения MODE.

`DAP_nRESET` формируется внешним NMOS 2N7002. PB12 DD2 подключается к gate через 1 кОм, gate подтянут к GND резистором 10 кОм, source соединён с GND, drain подключён к центральному контакту nRESET XP8. Высокий уровень PB12 открывает транзистор и притягивает nRESET к GND; при сбросе или отсутствии прошивки DD2 gate удерживается в нуле и nRESET отпущен. В макросе CMSIS-DAP логика PB12 должна быть инвертирована относительно физического уровня nRESET.

На стороне встроенного DAP подтяжка nRESET к `+3V3_DAP` не устанавливается. Локальная target имеет единственную подтяжку к `+3V3_TGT`, внешняя target должна иметь собственную подтяжку к своему VTref. Номинал локальной подтяжки ещё необходимо утвердить. По спецификации К1986ВЕ92FI низкий уровень длительностью не менее 200 нс гарантированно формирует сброс, а импульс не более 10 нс гарантированно игнорируется. До утверждения схемы остаётся выбрать ESD-защиту линии и решить, нужен ли внешний супервизор или автоматический reset после стабилизации `+3V3_TGT`.

На шелкографии должны различаться `TARGET_RESET`, `DAP_RESET` и положение полного отключения `TARGET_POWER`.

### 7.2. Сброс и программирование DAP MCU

NRST STM32F103 соединяется с GND конденсатором 100 нФ, выводится на XP5.5 как `DAP_MCU_NRST` и не имеет внешней подтяжки к `+3V3_DAP`. Отдельная кнопка RESET DAP не устанавливается. Обычная перезагрузка выполняется полным отключением питания всей отладочной платы.

XP5 выполняется как установленная однорядная гребёнка 1x5 с шагом 2,54 мм:

| Контакт XP5 | Сигнал | Назначение |
|---:|---|---|
| 1 | `+3V3_DAP` | VTref внешнего SWD-адаптера; не является входом питания платы |
| 2 | `DAP_MCU_SWDIO` | PA13/SWDIO DD2 |
| 3 | GND | Общая земля |
| 4 | `DAP_MCU_SWCLK` | PA14/SWCLK DD2 |
| 5 | `DAP_MCU_NRST` | NRST DD2 |

BOOT0 и PB2/BOOT1 постоянно удерживаются в нуле отдельными резисторами 10 кОм. XP9 и сервисный UART-разъём для системного загрузчика не устанавливаются. PA13 и PA14 не назначаются другим функциям; SWO самого DD2 на XP5 не выводится.

Перед сменой прошивки полностью отключают оба USB-C, VIN и внешние источники питания платы, устанавливают `DAP_ROUTE=OFF` и подключают внешний SWD-адаптер к XP5. Затем подают питание через USB-C DAP, выполняют erase/program/verify и снова полностью обесточивают плату перед отключением адаптера и восстановлением рабочей конфигурации.

## 8. USB-C и защита

USB-C DAP работает как постоянный Device/UFP/Sink с отдельными `Rd=5,1 кОм, 1 %` на CC1 и CC2. PA11/USBDM и PA12/USBDP подключаются к D-/D+ через последовательные резисторы 22 Ом. Обязательная подтяжка сети `DP_DAP_USB` сопротивлением 1,5 кОм к `+3V3_DAP` коммутируется P-MOSFET: source соединён с `+3V3_DAP`, drain — с резистором 1,5 кОм, gate через 1 кОм подключён к PB15 (`DAP_USB_PULLUP_EN_n`) и через 10 кОм — к source. Низкий уровень PB15 включает pull-up, высокий уровень или high-Z отключает его. До инициализации PB15 находится в высокоимпедансном состоянии, поэтому резистор gate-source удерживает P-MOSFET закрытым; прошивка включает подтяжку только после настройки USB и тактирования 48 МГц.

На линиях D+/D- каждого USB-C устанавливается отдельная малоёмкостная сборка `USBLC6-2SC6` по проходной схеме производителя: одна защищаемая линия проходит через пару `I/O1`, вторая — через пару `I/O2`, вывод `VBUS` подключается к соответствующему номинальному VBUS 5 В, вывод GND — непосредственно к общей земле. Дополнительная обвязка именно для `USBLC6-2SC6` не требуется; последовательные согласующие резисторы, CC-резисторы и элементы силового тракта выполняют другие функции и сохраняются. Сборка размещается непосредственно у разъёма, а её соединение с GND выполняется коротким и низкоиндуктивным.

D+ и D- являются низковольтными дифференциальными сигнальными линиями USB, а не логикой 5 В. `USBLC6-2SC6` ограничивает ESD-импульсы на D+/D- и VBUS, но не заменяет ограничитель тока, предохранитель или блокировку обратного питания силовой линии. Внешние напряжения выше номинальных 5 В VBUS не относятся к поддерживаемым режимам обоих USB-C.

USB-C target работает только как постоянный Device/UFP/Sink. На CC1 и CC2 устанавливаются отдельные `Rd=5,1 кОм, 1 %` к GND; `USB_VBUS` разъёма поступает непосредственно на вход T-селектора без дополнительного eFuse или ограничителя тока на плате. Режимы Host/DFP/Source и dual-role через этот разъём не поддерживаются, а прошивка К1986 должна оставлять `HSCR.HOST_MODE=0`.

Для USB-C DAP защита пользовательских выходов от короткого замыкания и обратного питания выполняется `TPS2553-1`; дополнительная блокировка обратного тока внутренних шин DAP не предусматривается. Для USB-C target дополнительная силовая защита VBUS не устанавливается: потребление должно укладываться в ток, разрешённый его USB-хостом после конфигурации; дескриптор DAP относится только к USB-C DAP. Контроль наличия VBUS и необходимость физической изоляции DP/DN с учётом errata 0033 К1986ВЕ92FI остаются открытыми. Экраны обоих USB-C соединяются с GND напрямую. Допустимые условия одновременного подключения к разным компьютерам подлежат проверке.

## 9. Проверки прототипа

До утверждения силовой части необходимо выполнить следующие проверки.

### 9.1. Источники и T-селектор

- проверить по отдельности питание от USB-C DAP, USB-C target и VIN;
- проверить отсутствие питания target при снятом джампере;
- подключить все три физических источника и проверить каждое положение селектора;
- измерить обратный ток во все невыбранные ветви;
- проверить подключение и отключение источников под нагрузкой;
- измерить пусковые токи, провалы, выбросы и время установления `+5V_TGT` и `+3V3_TGT`;
- проверить ошибочные положения джампера и невозможность соединения двух источников стандартным способом установки.

### 9.2. Нагрузка и аварийные режимы

- измерить выходные напряжения, пульсации и нагрев без shield и при максимальной заявленной нагрузке;
- проверить `LMR51410XDBVR` без нагрузки, при типовом потреблении К1986 50...100 мА и при максимальной полезной нагрузке 300 мА; отдельно измерить пульсации и поведение PFM при малой нагрузке;
- измерить нагрев `LMR51410XDBVR`, дросселя и `TLV76133DCYR` ветви `+3V3_TGT`;
- подтвердить токовые ограничения каждого USB-C; для ветви VIN зафиксировать отсутствие отдельного точного ограничителя тока и не проводить неконтролируемое испытание прямым коротким замыканием;
- подтвердить общий порог ограничения каждого из двух `TPS2553-1`, защёлкивание при КЗ и восстановление после переключения `EN` либо полного снятия питания;
- измерить обратный ток через `+5V_DAP_OUT` и `+3V3_DAP_OUT`, включая подачу внешнего напряжения при обесточенном USB-C DAP;
- проверить работу стабилизаторов при минимальном токе target;
- проверить отсутствие опасного напряжения на выходах выключенных преобразователей.

### 9.3. Power cycle и выключенные домены

- измерить время падения `+3V3_TGT` до требуемого порога при снятии джампера;
- подобрать номинал параллельного разрядного резистора;
- подтвердить повторное чтение MODE после выключения и включения при соблюдении документированной последовательности отключения внешних интерфейсов;
- измерить остаточное напряжение `+3V3_TGT` в штатной конфигурации power cycle; проверка произвольных сочетаний `DAP ON / target OFF` и `DAP OFF / target ON` не является критерием приёмки платы;
- проверить, что прямое питание BUcc от `+3V3_TGT` не мешает полному выключению и повторному чтению MODE; не подавать питание на контакт Morpho, связанный с BUcc;
- подтвердить, что индикатор target гаснет и не препятствует полному разряду.

### 9.4. VTref, RESET и USB

- проверить VTref локальной и внешней target во всех положениях XP8;
- проверить запрет активности DAP при отсутствующем или недопустимом VTref;
- проверить питание внешней target через отдельные контакты `+5V_DAP_OUT` и `+3V3_DAP_OUT` с GND соседнего `SPARE JMP`, включая распределение общего токового бюджета, падение напряжения, КЗ и ошибочное одновременное подключение собственного источника;
- проверить кнопку, встроенный DAP, внешний DAP, удержание reset и connect-under-reset;
- подтвердить физический разрыв локального и внешнего nRESET;
- проверить USB enumeration, ESD-защиту, VBUS sense и отсутствие обратного тока в оба USB-кабеля;
- проверить матрицу состояний DAP, локальной target, внешней target на XP7 и внешнего DAP на ARM 10-pin.

Измеренные пороги, токи, временные параметры и температуры добавляются в этот документ после испытаний прототипа.

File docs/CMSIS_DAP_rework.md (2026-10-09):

# Замена встроенного ST-Link на CMSIS-DAP в MDR32 MILUINO

## 1. Статус документа

Этот документ описывает предлагаемую переработку встроенного отладчика MDR32 MILUINO для работы с CMSIS-DAP и OpenOCD. Это проектное предложение, а не утверждённая принципиальная схема или готовый нетлист.

Для текущей ревизии приняты следующие исходные решения:

1. микроконтроллер встроенного DAP остаётся существующим STM32F103 (DD2); переход на второй К1986ВЕ92FI отложен на будущую ревизию;
2. карта выводов, коммутация VCP, MODE[2:0], JTAG_A/JTAG_B и локальных функций должны соответствовать актуальному `MDR32_MILUINO_pin_mapping.md`;
3. встроенный CMSIS-DAP работает с target только по SWD; переход с ST-Link на CMSIS-DAP не меняет физический протокол SWD между программатором и К1986ВЕ92FI;
4. JTAG_A/OFF/JTAG_B выбирается согласованной группой из пяти трёхконтактных джамперных селекторов; снятые джамперы образуют состояние OFF;
5. MODE[2:0] задаются только локальными конфигураторами и не выводятся на Morpho;
6. существующий шестиконтактный XP7 и его ST-Link-совместимая распиновка сохраняются для программирования внешних плат на К1986 встроенным DAP;
7. XP8 перерабатывается в пассивный пятиканальный селектор `DAP_ROUTE=EXTERNAL/OFF/TARGET` на гребёнке 3x5 с отдельными джамперами для SWCLK, SWDIO, nRESET, VTref и SWO;
8. стандартный ARM Cortex Debug 10-pin 2x5 с шагом 1,27 мм добавляется как отдельный разъём на общей DBG-шине и не заменяет XP8;
9. полный четырёхпроводный JTAG локального К1986 доступен внешнему отладчику через ARM 10-pin; `nTRST` на этот разъём не выводится;
10. SWO поддерживается от активного порта К1986 через совмещённую линию TDO/SWO и коммутируется пятой строкой XP8;
11. CDC ACM/VCP сохраняется на PD0/PD1 через согласованные пары R1005/R1105 и R1006/R1106;
12. встроенный STM32F103 первоначально прошивается, восстанавливается и отлаживается внешним SWD-адаптером через отдельный разъём XP5 1x5 с шагом 2,54 мм; системный UART-загрузчик, переключатель BOOT0 и отдельная кнопка RESET DAP не используются;
13. разъём USB встроенного DAP заменяется на USB-C Device;
14. индикация DAP выполняется по аналогии с STM Nucleo: двухцветный красно-зелёный COM LED и отдельная индикация питания при необходимости;
15. штатный локальный отладочный профиль - `MODE=001`, `DBG_PORT_SEL=A`; после изменения MODE выполняется полный power cycle target.
16. XP7 принимает `EXT_VTREF` от внешней target и не передаёт ей питание; для намеренного питания от программатора используются отдельные контакты `+5V_DAP_OUT` и `+3V3_DAP_OUT`, а GND берётся с расположенного рядом `SPARE JMP`.
17. поддерживается только внешняя target с номинальным напряжением 3,3 В; наличие VTref определяется дискретной транзисторной схемой, без измерения точного значения АЦП.

До выпуска схемы необходимо совместно утвердить:

1. достаточность Flash/RAM и периферии точной установленной модификации STM32F103 для CMSIS-DAP v2, CDC/VCP, SWO и принятой индикации;
2. конкретные компоненты, номиналы и оставшиеся вопросы защиты питания, VTref и nRESET из отдельного документа [CMSIS_DAP_power_reset_questions.md](CMSIS_DAP_power_reset_questions.md); структурная архитектура источников и доменов питания уже согласована;
3. окончательные номиналы последовательных резисторов, параметры ESD-защиты и допустимую частоту SWD/JTAG по результатам измерений;
4. конфигурацию OpenOCD и работу программирования, восстановления и SWO на реальном К1986ВЕ92FI.

## 2. Термины и границы задачи

CMSIS-DAP и OpenOCD выполняют разные функции:

- **CMSIS-DAP** - протокол и прошивка USB-отладчика на плате;
- **OpenOCD** - программа на компьютере, которая управляет CMSIS-DAP, ядром Cortex-M3 и Flash-памятью К1986ВЕ92FI;
- **К1986ВЕ92FI** - целевой микроконтроллер;
- **DAP MCU** - отдельный микроконтроллер встроенного программатора, в текущей ревизии сохраняемый DD2 семейства STM32F103;
- **VCP** - виртуальный COM-порт между USB и UART целевого МК;
- **VTref** - напряжение целевой стороны 3,3 В, используемое отладчиком для контроля наличия опорного логического уровня. Это не выход питания внешней платы; target с логикой 1,8 В или 2,5 В не поддерживаются;
- **DAP_ROUTE** - переработанный XP8, выбирающий подключение встроенного DAP к XP7, полное отключение либо подключение к локальной DBG-шине;
- **DBG_PORT_SEL** - отдельный пятиканальный селектор локального порта К1986: JTAG_A/OFF/JTAG_B.

Замена ST-Link на OpenOCD не выполняется одной заменой программы на компьютере. На плате должен находиться совместимый USB-адаптер, в данном случае CMSIS-DAP, а OpenOCD должен иметь подходящую конфигурацию target и Flash для К1986ВЕ92FI.

## 3. Исходная реализация

Источники:

- [принципиальная схема ДФТВ.434519.003Э3](../datasheets/ДФТВ.434519.003Э3.pdf), лист 2;
- [паспорт ДФТВ.434519.003ПС](../datasheets/ДФТВ.434519.003ПС.pdf), страницы PDF 8-9;
- [спецификация К1986ВЕ92FI](../datasheets/К1986ВЕ92FI,%20К1986ВЕ92F1I,%20К1986ВЕ94GI.pdf), страницы PDF 74-76, таблицы 12 и 13.

### 3.1. Текущая структура

```text
USB mini-B XS5
      |
      v
STM32F103 DD2 с прошивкой ST-Link
      |
      +---- XP7: выход встроенного ST-Link на внешнюю target-плату
      |
      +---- XP8: две перемычки SWCLK и SWDIO
                    |
                    v
              К1986ВЕ92FI, PD1/PD0, JTAG_B/SWD
```

DD2 одновременно обслуживает:

- USB-интерфейс встроенного ST-Link;
- SWD целевого микроконтроллера;
- UART/VCP;
- светодиод состояния;
- BOOT0 и служебные точки собственного программирования.

### 3.2. XP7

Текущий XP7 - шестиконтактный выход встроенного ST-Link для внешней целевой платы.

| Контакт | Сигнал | Назначение |
|---:|---|---|
| 1 | EXT_VTREF | Опорное напряжение внешней target-платы |
| 2 | SWCLK | Тактовый сигнал SWD |
| 3 | GND | Общий провод |
| 4 | SWDIO | Двунаправленные данные SWD |
| 5 | NRST | Сброс target |
| 6 | SWO | Трассировочный вход встроенного ST-Link |

XP7 не является полноценным JTAG-разъёмом: на нём отсутствуют отдельные TDI, TDO и nTRST. Он также не является безопасным входом внешнего адаптера к установленному К1986ВЕ92FI, потому что остаётся соединён с выходами DD2.

### 3.3. XP8

Текущий XP8 содержит две независимые двухконтактные перемычки.

| Контакты | Соединение |
|---|---|
| 1-2 | `SWCLK` встроенного ST-Link - `SWCLK_TARG` К1986ВЕ92FI |
| 3-4 | `SWDIO` встроенного ST-Link - `SWDIO_TARG` К1986ВЕ92FI |

При замкнутом XP8:

- SWCLK приходит на PD1/JB_TCK, физический вывод 32;
- SWDIO приходит на PD0/JB_TMS, физический вывод 31;
- используется JTAG_B в двухпроводном режиме SWD.

XP8 разрывает только SWCLK и SWDIO. Он не обеспечивает полную изоляцию NRST, SWO, питания и остальных линий JTAG.

### 3.4. Ограничения существующего решения

1. Используется только JTAG_B/SWD на PD0 и PD1.
2. Полный пятисигнальный JTAG к К1986ВЕ92FI не разведён.
3. PD0-PD4 конфликтуют с ADC0-ADC4 и внешней опорой ADC0_REF+/ADC1_REF-.
4. Нет аппаратного выбора JTAG_A/JTAG_B.
5. После снятия XP8 отсутствует полноценный вход внешнего адаптера к установленному target.
6. Подключение внешнего адаптера к XP7 может создать конфликт его выходов с выходами DD2.
7. Нет состояния, в котором все отладочные линии гарантированно электрически отключены от target.
8. Не предусмотрена защита от подпитки выключенного target через отладочные GPIO.
9. MODE[2:0] зафиксированы в `000`, поэтому после включения выбирается JTAG_B.

## 4. Целевая архитектура

### 4.1. Функциональная схема

```text
                         USB-C DAP
                             |
                             v
                   STM32F103, CMSIS-DAP
                     SWD + SWO + VCP
                             |
                    XP8 / DAP_ROUTE 3x5
               EXTERNAL / OFF / TARGET
                    /                   \
                   v                     v
          XP7, 1x6 SWD              общая DBG-шина <---- ARM Cortex Debug 10-pin
          внешняя target                    |
                                      DBG_PORT_SEL
                                      A / OFF / B
                                       /       \
                                      v         v
                              JTAG_A PB0-PB4  JTAG_B PD0-PD4

MODE[2:0] --------------------> отдельный механический конфигуратор
VCP через R1105/R1106 ----------> PD0/PD1 независимо от DAP_ROUTE
```

Встроенный DAP формирует только SWD и не обязан реализовывать JTAG. Полный четырёхпроводный JTAG доступен внешнему отладчику через дополнительный ARM 10-pin. Этот разъём постоянно подключён к общей DBG-шине перед `DBG_PORT_SEL` и не заменяет XP8.

XP7 используется как выход встроенного DAP на внешнюю target-плату. Вход внешнего DAP к локальному К1986 выполняется через ARM 10-pin, а не через XP7.

### 4.2. Состояния коммутации

| Задача | DAP_ROUTE / XP8 | DBG_PORT_SEL | MODE[2:0] | Разъём |
|---|---|---|---|---|
| Встроенный DAP -> локальный К1986 через JTAG_A/SWD | TARGET | A | 001 | USB-C DAP |
| Встроенный DAP -> локальный К1986 через JTAG_B/SWD | TARGET | B | 000 | USB-C DAP |
| Внешний DAP -> локальный К1986 через JTAG_A | OFF | A | 001 | ARM 10-pin |
| Внешний DAP -> локальный К1986 через JTAG_B | OFF | B | 000 | ARM 10-pin |
| Встроенный DAP -> внешняя target | EXTERNAL | OFF рекомендуется | Не влияет на внешнюю плату | XP7 |
| Полное отключение встроенного DAP и локальных JTAG-ветвей | OFF | OFF | Любое | Разъёмы свободны |

Для внешнего DAP допускаются SWD и обычный четырёхпроводный JTAG. Стандартный ARM 10-pin не содержит nTRST; сброс TAP выполняется последовательностью TMS/TCK, а локальный nTRST остаётся подтянутым к питанию.

Запрещённые сочетания:

- `DAP_ROUTE=TARGET` при подключённом активном внешнем DAP к ARM 10-pin;
- смешанные положения пяти джамперов XP8;
- два джампера в одной строке XP8, соединяющие внешнюю и локальную target;
- `DBG_PORT_SEL=A` вместе с `MODE=000`;
- `DBG_PORT_SEL=B` вместе с `MODE=001`;
- одновременная установка джамперов A и B в одной строке `DBG_PORT_SEL`.

### 4.3. Пути программирования локального К1986ВЕ92FI

```mermaid
flowchart TB
    PC["ПК / OpenOCD / IDE"] -->|"USB"| ONBOARD["Встроенный CMSIS-DAP"]
    PC -->|"USB"| EXTERNAL["Внешний DAP"]
    ONBOARD -->|"DAP_ROUTE=TARGET"| DBG["Общая DBG-шина"]
    EXTERNAL -->|"ARM 10-pin, DAP_ROUTE=OFF"| DBG
    DBG --> SEL{"DBG_PORT_SEL"}
    SEL -->|"A + MODE=001"| JA["JTAG_A / PB0-PB4"]
    SEL -->|"B + MODE=000"| JB["JTAG_B / PD0-PD4"]
    JA --> CORE["Debug Cortex-M3"]
    JB --> CORE
    CORE --> FLASH["Flash К1986"]
```

Встроенный DAP использует линии SWCLK, SWDIO, nRESET, VTref и вход SWO. Внешний DAP через ARM 10-pin дополнительно использует TDI и TDO для JTAG. Выбранный TDO локального К1986 работает как SWO после перехода интерфейса в SWD.

### 4.4. Программирование внешней target-платы встроенным DAP

```text
ПК -> USB-C -> встроенный CMSIS-DAP -> DAP_ROUTE=EXTERNAL -> XP7 -> внешняя target
```

Для этого:

- все пять джамперов XP8 устанавливаются в положение EXTERNAL;
- SWCLK, SWDIO, nRESET и SWO соединяются только с XP7;
- VTref поступает от внешней target через XP7 только как опорный уровень;
- локальная DBG-шина физически отключена от встроенного DAP;
- питание внешней target через XP7 не подаётся;
- при необходимости внешняя target получает питание через отдельные контакты `+5V_DAP_OUT` и `+3V3_DAP_OUT`; GND берётся с расположенного рядом `SPARE JMP`.

### 4.5. Органы переключения на плате

| Орган | Физическое исполнение | Что переключает | Примечание |
|---|---|---|---|
| MODE[2:0] | Три механических 0/1 конфигуратора или джампера | PF4/MODE0, PF5/MODE1, PF6/MODE2 | Новое состояние применяется только после полного power cycle Ucc target |
| DAP_ROUTE / XP8 | Гребёнка 3x5, шаг 2,54 мм, пять джамперов | SWCLK, SWDIO, nRESET, VTref, SWO между XP7, DAP и локальной DBG-шиной | Все пять джамперов устанавливаются одинаково либо снимаются |
| DBG_PORT_SEL | Пять трёхконтактных джамперных селекторов `A-COM-B`; без джамперов - OFF | TCK, TMS/SWDIO, TDI, TDO/SWO и nTRST | Положение должно совпадать с MODE=001/000 |
| R1009/R1109 AREF | Штатный R1009 и неустановленный R1109 | R1009 соединяет Arduino AREF с `+3V3_TGT`; R1109 ведёт к PD0/JB_TMS_Line | В режиме MODE=101 R1109 не устанавливать; будущая внешняя опора использует R1109+R1005 и уже предусмотренный в схеме R1206=0 Ом (DNP) от PD1 к GND |
| SEL_D11_SPI_PWM | Существующий селектор PF0/PA1 | PF0 либо PA1 к D11 | Для MODE=110 выбрать PA1 либо отключить внешнюю нагрузку PF0 |
| D13/SCK | Прямая сеть PF1 | PF1 к D13 | Для MODE=110 внешние устройства должны быть отключены |

На шелкографии XP8 достаточно подписать столбцы `EXT | DAP | LOCAL` и строки `CLK`, `DIO`, `RST`, `REF`, `SWO`. Полная таблица допустимых положений приводится в документации платы. Джамперы нельзя парковать поперёк строк; при необходимости предусматривается отдельная электрически изолированная парковочная колодка.

## 5. Сохранение DD2 STM32F103

В текущей ревизии существующий DD2 STM32F103 сохраняется и переводится с закрытой прошивки ST-Link на CMSIS-DAP. Переход на второй К1986ВЕ92FI либо другой DAP MCU отложен на будущую ревизию.

До фиксации состава прошивки необходимо определить точную модификацию установленного STM32F103 и подтвердить доступный объём Flash/RAM. Сохраняемый DD2 должен обеспечивать:

- USB Device для CMSIS-DAP v2 и CDC ACM/VCP;
- достаточный объём Flash и RAM для CMSIS-DAP, VCP, SWO и индикации;
- GPIO для SWCLK, двунаправленного SWDIO и управления nRESET;
- вход, пригодный для захвата SWO;
- штатный SWD на PA13/PA14 и NRST, выведенный на отдельный разъём XP5 1x5 с шагом 2,54 мм;
- возможность первичной прошивки, восстановления и полной отладки внешним SWD-адаптером;
- предсказуемое high-Z состояние отладочных выводов при сбросе и выключенном питании target.

Несмотря на сохранение DD2, его USB-обвязка, питание, тактирование, цепи загрузки и производственного программирования перерабатываются под новую схему. Если точная модификация STM32F103 не вмещает выбранный набор функций, сначала сокращается состав дополнительных функций DAP; замена микроконтроллера относится к отдельной будущей ревизии.

### 5.1. Согласованная аппаратная реализация DD2

Для текущей ревизии зафиксирована следующая карта аппаратных функций STM32F103CBU6:

| Функция | Вывод DD2 | Реализация |
|---|---|---|
| USB D- | PA11 | через 22 Ом к USB-C, малоёмкостная ESD-защита у разъёма |
| USB D+ | PA12 | сеть `DP_DAP_USB`, через 22 Ом к USB-C; внешняя подтяжка 1,5 кОм через управляемый P-MOSFET |
| управление USB pull-up | PB15 | `DAP_USB_PULLUP_EN_n`, gate через 1 кОм, gate-source 10 кОм, активный низкий уровень |
| SWCLK target | PB13 | push-pull через 22-47 Ом к XP8.7 |
| SWDIO target | PB14 | один двунаправленный GPIO через 22-47 Ом к XP8.8 |
| nRESET target | PB12 | через 1 кОм на gate 2N7002; gate 10 кОм к GND, source к GND, drain к XP8.9 |
| SWO target | PB11/USART3_RX | от XP8.10 через начальный последовательный резистор 100 Ом |
| наличие VTref | PA0 | активный низкий `nDAP_VTREF_PRESENT` от NMOS-детектора |
| VCP | PA2/USART2_TX, PA3/USART2_RX | через XP6 и альтернативные R1105/R1106 к UART2 target |
| логгер DAP | PA9/USART1_TX; PA10/USART1_RX | `DAP_LOG_TX` и `DAP_LOG_RX`; реализация должна быть неблокирующей |
| управление питанием от DAP | PA1 | `DAP_TARGET_PWR_EN`, активный высокий уровень; напрямую на `EN` первого TPS2553-1 внешних выходов DAP и через NMOS 2N7002 на gate силового P-MOSFET ветви К1986; ко второму TPS2553-1 ветви Output Power не подключён |
| индикатор COM | GPIO не выбран | `DAP_COM_LED` сохраняется; вывод и схема подключения утверждаются отдельно |
| MCO target | PA8/MCO | `R109=22 Ом`, `DAP_MCO_Line`, R1003=0 Ом; отдельный `R_EN_DAP` не устанавливается |
| сервисный SWD DD2 | PA13, PA14, NRST | установленный разъём XP5 1x5 с шагом 2,54 мм вместе с `+3V3_DAP` и GND |

PB12 используется только для управления внешним NMOS линии nRESET. CMSIS-DAP переключает PB14 между push-pull output и floating input; при переходе линии к target и обратно используются turnaround-такты SWD. Внутренняя подтяжка PB14 не включается: неактивное состояние задаёт внешняя подтяжка 100 кОм на target-стороне. Перед переводом PB14 в выход прошивка сначала записывает требуемый уровень в выходной регистр, затем включает push-pull, чтобы исключить короткий импульс.

Питание DD2 выполняется от `+3V3_DAP`: возле каждого VDD устанавливается 100 нФ, общий конденсатор составляет 4,7...10 мкФ, возле VDDA/VSSA устанавливаются 100 нФ и 1 мкФ, VBAT соединяется с `+3V3_DAP` и развязывается 100 нФ. Открытая площадка UFQFPN48 соединяется с GND. Основной генератор использует кварц 8 МГц; нагрузочные ёмкости рассчитываются по параметру `CL` выбранного кварца. NRST DD2 имеет конденсатор 100 нФ к GND, подключается к XP5 и не требует внешней подтяжки. Отдельная кнопка RESET DAP не устанавливается; для обычного перезапуска DAP полностью отключается питание платы.

## 6. Требования к прошивке CMSIS-DAP

В прошивке должны быть реализованы:

1. CMSIS-DAP v2 через USB bulk;
2. транспорт SWD и последовательность переключения JTAG -> SWD, необходимая при подключении к К1986ВЕ92FI;
3. управление nRESET;
4. захват SWO от target;
5. CDC ACM/VCP для UART2 target через PD0/PD1;
6. перевод всех отладочных выходов в безопасное состояние при старте, USB disconnect и ошибке;
7. корректное описание возможностей SWD, SWO и UART через команды DAP_Info;
8. уникальный USB serial number;
9. управление индикацией COM по аналогии с STM Nucleo;
10. ограничение начальной частоты SWD до заведомо устойчивого значения.
11. неблокирующий двунаправленный логгер DAP через USART1_TX на PA9 и USART1_RX на PA10; переполнение его программного буфера не должно задерживать USB, SWD или SWO.

CMSIS-DAP v1 через HID в текущую прошивку не включается. Основной и единственный DAP-транспорт — CMSIS-DAP v2 через USB bulk; для Full-Speed USB используется `DAP_PACKET_SIZE=64`, а `DAP_PACKET_COUNT` выбирается после оценки расхода 20 Кбайт SRAM. В конфигурации возможностей устанавливаются `DAP_SWD=1` и `DAP_JTAG=0`.

Полный JTAG во встроенной прошивке не требуется. Он остаётся доступен внешнему отладчику через ARM 10-pin.

### 6.1. Индикация DAP

Функционально воспроизводится индикация ST-LINK/V2-1 на Nucleo:

- медленное мигание красным - запуск до инициализации USB;
- быстрое мигание красным - USB enumeration;
- красный - USB/CMSIS-DAP инициализирован, target ещё не подтверждён;
- зелёный - связь с target установлена либо операция завершена успешно;
- чередование красного и зелёного - обмен с target;
- визуально оранжевый - ошибка.

Используется двухцветный красно-зелёный COM LED с отдельными токоограничивающими резисторами. Номиналы выбираются по яркости конкретного светодиода, а не копируются автоматически со схемы Nucleo. Отдельный `DAP_POWER` допускается как независимый индикатор питания.

## 7. Полная отладочная шина

### 7.1. Обязательные сигналы

| Сеть общей шины | Направление относительно DAP | JTAG_A К1986 | JTAG_B К1986 | Примечание |
|---|---|---|---|---|
| DBG_TCK_SWCLK | DAP -> target | PB2, вывод 45 | PD1, вывод 32 | TCK в JTAG, SWCLK в SWD |
| DBG_TMS_SWDIO | Двунаправленный в SWD | PB1, вывод 44 | PD0, вывод 31 | В JTAG DAP -> target как TMS |
| DBG_TDI | DAP -> target | PB3, вывод 46 | PD3, вывод 34 | Нужен для полного JTAG |
| DBG_TDO_SWO | target -> DAP | PB0, вывод 43 | PD4, вывод 30 | TDO в JTAG, SWO в SWD |
| DBG_nTRST | Внешний JTAG / подтяжка -> target | PB4, вывод 47 | PD2, вывод 33 | На ARM 10-pin не выводится; для штатной работы удерживается неактивным подтяжкой |
| DBG_nRESET | DAP -> target | RESET, вывод 18 | RESET, вывод 18 | Общий для A/B, управление open-drain; от встроенного DAP отключается XP8 |
| DBG_VTREF | target -> DAP | +3V3_TGT | +3V3_TGT | Только опорный уровень, не питание target |
| GND | Общий | GND | GND | Несколько контактов на внешнем разъёме |

В режиме SWD активная линия TDO выбранного порта используется как SWO: `PB0/JA_TDO` для JTAG_A либо `PD4/JB_TDO` для JTAG_B. В режиме JTAG та же сеть передаёт TDO и не может одновременно использоваться как SWO.

### 7.2. Подтяжки и последовательные резисторы

Спецификация К1986ВЕ92FI требует подтяжки линий JTAG к питанию сопротивлениями не менее 10 кОм и показывает типовую сеть 100 кОм. Для новой платы принято:

- установить подтяжки 100 кОм к +3,3 В для TMS/SWDIO, TCK/SWCLK, TDI, TDO/SWO и nTRST на общей стороне `DBG_PORT_SEL`, чтобы они действовали только на выбранный JTAG-порт;
- не оставлять постоянные подтяжки на PD0-PD4, когда JTAG_B отключён, поскольку эти выводы используются АЦП и внешней опорой;
- предусмотреть посадочные места последовательных резисторов 22-47 Ом прежде всего на SWCLK/TCK, а при необходимости также на SWDIO, TMS, TDI, TDO/SWO и nRESET;
- окончательные номиналы выбрать после проверки фронтов и устойчивой частоты SWD/JTAG.

Подтяжка RESET должна оставаться на target-стороне независимо от выбранного JTAG-порта. Между локальной сетью `TARGET_nRESET` и GND возле К1986 устанавливается C1 номиналом 100 нФ, X7R для фильтрации помех и дребезга кнопки; кнопка, встроенный DAP, внешний DAP и shield могут только притягивать линию к GND, а активный высокий уровень и подтяжка к 5 В запрещены.

На пользовательских разъёмах XP7 и ARM 10-pin предусматривается малоёмкостная ESD-защита. Последовательные резисторы используются для согласования фронтов и не заменяют полноценную ESD-защиту.

## 8. Изоляция встроенного DAP

Аппаратная изоляция встроенного DAP выполняется пассивным селектором XP8/DAP_ROUTE. В положении OFF физически разрываются все пять цепей встроенного DAP: SWCLK, SWDIO, nRESET, VTref и SWO. Перевод GPIO STM32 в input не используется как единственное средство отключения.

В положении EXTERNAL эти цепи соединяются только с XP7, а в положении TARGET - только с локальной DBG-шиной. Пассивная коммутация подходит для двунаправленного SWDIO и не добавляет утечку либо паразитную ёмкость электронного mux на аналоговые выводы JTAG_B.

`DAP_nRESET` формируется внешним NMOS 2N7002: PB12 подключается к gate через 1 кОм, gate подтянут к GND резистором 10 кОм, source соединён с GND, drain — с центральным контактом nRESET XP8. Высокий уровень PB12 активирует физический низкий уровень nRESET; макрос CMSIS-DAP должен учитывать эту инверсию. Подтяжка nRESET остаётся на target-стороне и не подключается к `+3V3_DAP`.

VTref от внешней и локальной target не соединяются: XP8 выбирает ровно один источник опорного уровня для встроенного DAP. Поддерживается только target с логикой 3,3 В. Номинальное значение внешнего `EXT_VTREF` равно 3,3 В, рабочий ориентир — 3,0...3,6 В. После XP8 выбранный `DAP_VTREF` через последовательный резистор 1 кОм подключается к gate NMOS; gate подтянут к source резистором 10 кОм, source соединён с GND, drain подключён к PA0 и подтянут к `+3V3_DAP` резистором 10 кОм. При наличии VTref формируется `nDAP_VTREF_PRESENT=0`, при отсутствии — `nDAP_VTREF_PRESENT=1`. Для номинального VTref 3,3 В напряжение gate составляет около 3,0 В, поэтому конкретный NMOS должен иметь гарантированную работоспособность при таком уровне.

NMOS-узел является детектором присутствия и не гарантирует порог 3,0 В: target с логикой 1,8 В или 2,5 В может быть ошибочно распознана как включённая. Компаратор не устанавливается; ограничение «только target 3,3 В» является обязательным эксплуатационным условием. Специальная аппаратная защита от междоменной подпитки не предусматривается; принятый риск и ограничения эксплуатации приведены в [CMSIS_DAP_power_reset_questions.md](CMSIS_DAP_power_reset_questions.md).

## 9. Коммутация JTAG_A/OFF/JTAG_B

Принятая реализация соответствует актуальному `MDR32_MILUINO_pin_mapping.md`: пять общих сигналов TCK, TMS/SWDIO, TDI, TDO/SWO и nTRST проходят через пять одинаковых трёхконтактных джамперных селекторов `A-COM-B`.

Состояния каждого селектора:

- джампер `A-COM` подключает соответствующую линию JTAG_A;
- джампер `COM-B` подключает соответствующую линию JTAG_B;
- снятый джампер образует разрыв.

В штатной эксплуатации все пять джамперов должны находиться в одном согласованном состоянии: A, B либо OFF. Смешанная конфигурация допускается только как специальный диагностический режим. Одновременное соединение одной общей линии с A и B запрещено конструкцией трёхконтактного селектора.

Преимущества принятого варианта:

- отсутствуют утечка и паразитная ёмкость электронного mux на PD0-PD4;
- сохраняется качество аналоговых измерений при отключённом JTAG_B;
- состояние соединений доступно визуальному контролю и измерениям.

Недостаток — необходимость согласованно переставлять пять джамперов. На шелкографии должна быть единая маркировка `A / OFF / B` и сочетания `A+MODE001`, `B+MODE000`.

nRESET и VTref не переключаются между JTAG_A и JTAG_B, поскольку являются общими для локального К1986. Выбор между локальными nRESET/VTref и соответствующими цепями внешней target выполняет отдельный XP8/DAP_ROUTE.

## 10. MODE[2:0]

MODE0, MODE1 и MODE2 находятся соответственно на PF4, PF5 и PF6, физических выводах 6, 7 и 8.

Предлагаемая реализация:

- три независимых механических конфигуратора 0/1;
- определённые внешние pull-down для штатного состояния;
- возможность подать логическую 1 через переключатель и резистор к +3,3 В;
- тестовые точки на всех MODE;
- полная электрическая изоляция PF4-PF6 от Morpho, BOOT0 и внешних GPIO;
- таблица режимов на шелкографии.

Критичные режимы:

| MODE[2:0] | Запуск | Активный JTAG | Последствия |
|---|---|---|---|
| 000 | Внутренняя Flash | JTAG_B | PD0-PD4 заняты отладкой |
| 001 | Внутренняя Flash | JTAG_A | PD0-PD7 доступны аналоговой подсистеме |
| 101 | UART2 loader | Нет JTAG | PD0/PD1 заняты UART-загрузчиком |
| 110 | UART2 loader | Нет JTAG | PF0/PF1 заняты UART-загрузчиком |
| 111 | Тестовый режим | JTAG_A TAP | Не использовать как штатный режим |

Состояние MODE учитывается только при первоначальном включении. После установки FPOR обычного RESET недостаточно: для применения нового положения MODE необходимо полностью отключить основное питание Ucc К1986ВЕ92FI и включить его снова.

Следовательно, на плате нужен доступный способ гарантированно разорвать все источники питания target. Эту функцию выполняет T-образный селектор источника: при снятом джампере его общий выход `+5V_TGT` отключён от USB target, USB DAP и VIN. Для гарантированного разряда `+3V3_TGT` предусматривается постоянный параллельный резистор на GND.

Принятый штатный профиль:

- `MODE=001`;
- `DBG_PORT_SEL=A`;
- `DAP_ROUTE=TARGET` для работы встроенным DAP либо `DAP_ROUTE=OFF` для внешнего отладчика.

Он освобождает PD0-PD4 для AREF и аналоговых контактов, но занимает PB0-PB4 интерфейсом JTAG_A.

## 11. Сохраняемый XP7

Форм-фактор, количество контактов и распиновка существующего XP7 сохраняются:

| Контакт | Сигнал | Назначение |
|---:|---|---|
| 1 | EXT_VTREF | Опорное напряжение внешней target-платы |
| 2 | SWCLK | Тактовый сигнал SWD |
| 3 | GND | Общий провод |
| 4 | SWDIO | Двунаправленные данные SWD |
| 5 | nRESET | Сброс target |
| 6 | SWO | Трассировка от target к DAP |

XP7 остаётся шестиконтактным SWD-разъёмом для внешних плат на К1986 без собственного программатора. Выводы TDI и nTRST на него не добавляются; полный четырёхпроводный JTAG через XP7 не поддерживается. Контакт 6 сохраняется как SWO.

При `DAP_ROUTE=EXTERNAL` встроенный CMSIS-DAP программирует внешнюю target по SWD и при необходимости принимает её SWO. При `DAP_ROUTE=TARGET` и `DAP_ROUTE=OFF` XP7 физически отключён от сигнальных цепей встроенного DAP.

`EXT_VTREF` на XP7 используется только как опорный логический уровень от внешней target к встроенному DAP. Питание внешней target-платы через XP7 не предусматривается; для этого используются отдельные контакты `+5V_DAP_OUT` и `+3V3_DAP_OUT`, а GND берётся с расположенного рядом `SPARE JMP`.

## 12. XP8 и дополнительный ARM 10-pin

### 12.1. Переработанный XP8 / DAP_ROUTE

Текущий четырёхконтактный XP8 заменяется гребёнкой 3x5 с шагом 2,54 мм. Центральный столбец подключён к встроенному DAP, внешние столбцы - к XP7 и локальной DBG-шине.

| Строка | EXT | DAP | LOC |
|---|---|---|---|
| SWCLK | XP7.2 | DAP_SWCLK | DBG_TCK_SWCLK |
| SWDIO | XP7.4 | DAP_SWDIO | DBG_TMS_SWDIO |
| nRESET | XP7.5 | DAP_nRESET | DBG_nRESET |
| VTref | XP7.1 `EXT_VTREF` | DAP_VTREF | LOC_VTREF / DBG_VTREF |
| SWO | XP7.6 | DAP_SWO_RX | DBG_TDO_SWO |

Состояния каждой строки:

- джампер `EXTERNAL-DAP` - работа встроенного DAP с XP7;
- джампер `DAP-TARGET` - работа встроенного DAP с локальной DBG-шиной;
- джампер снят - OFF.

В штатной эксплуатации все пять джамперов находятся в одном положении либо сняты. Смешанные положения и установка двух джамперов в одной строке запрещены. Правильные сочетания приводятся в документации платы; на шелкографии остаются обозначения столбцов и строк.

### 12.2. ARM Cortex Debug 10-pin

На общую DBG-шину добавляется отдельный стандартный разъём ARM Cortex Debug 10-pin 2x5 с шагом 1,27 мм:

| Контакт | Сигнал |
|---:|---|
| 1 | VTref |
| 2 | TMS/SWDIO |
| 3 | GND |
| 4 | TCK/SWCLK |
| 5 | GND |
| 6 | TDO/SWO |
| 7 | KEY, контакт отсутствует |
| 8 | TDI |
| 9 | GND |
| 10 | nRESET |

Позиция 7 используется как механический ключ: электрический вывод в УГО и контактная площадка в посадочном месте отсутствуют, а в самом разъёме платы не должно быть металлического штыря 7. Контакт 9 подключается непосредственно к GND платы; внешний отладчик может использовать его как GNDDetect. Позицию KEY и контакт 9 запрещено переиспользовать под nTRST. Разъём обеспечивает SWD и обычный четырёхпроводный JTAG. Для внешнего отладчика XP8 устанавливается в OFF, затем `DBG_PORT_SEL` и MODE выбирают JTAG_A либо JTAG_B. Ответвление от общей DBG-шины к разъёму должно быть коротким, особенно для TCK/SWCLK.

## 13. USB и питание DAP

### 13.1. USB-C вместо XS5 mini-B

Принят переход с XS5 mini-B на USB-C в роли USB Device. Необходимо:

- отдельные Rd 5,1 кОм, 1 % на CC1 и CC2;
- отдельная малоёмкостная ESD-сборка `USBLC6-2SC6` на D+ и D- каждого USB-C;
- последовательные резисторы 22 Ом между PA11/PA12 и D-/D+;
- внешняя подтяжка сети `DP_DAP_USB` сопротивлением 1,5 кОм к `+3V3_DAP` через P-MOSFET под управлением PB15; source P-MOSFET подключён к `+3V3_DAP`, drain — к резистору 1,5 кОм, gate через 1 кОм — к `DAP_USB_PULLUP_EN_n` и через 10 кОм — к source;
- отсутствие длинных ответвлений на D+/D-;
- дифференциальная трассировка около 90 Ом;
- экраны обоих USB-C напрямую соединены с GND;
- номинальный VBUS 5 В без поддержки USB Power Delivery и повышенных напряжений.

PB15 использует активный низкий уровень: низкий уровень открывает P-MOSFET и подключает pull-up D+, высокий уровень либо high-Z отключает его. После сброса PB15 является высокоимпедансным входом, поэтому резистор gate-source 10 кОм удерживает P-MOSFET закрытым и не позволяет компьютеру обнаружить устройство до готовности прошивки. При инициализации прошивка сначала записывает единицу в выходной регистр PB15, затем переводит вывод в push-pull output и устанавливает ноль только после настройки USB и тактирования 48 МГц. Схема обеспечивает программную re-enumeration и отсутствие преждевременного подключения USB.

### 13.2. Домены питания

Структурная архитектура питания согласована; принятые компоненты, номиналы и остающиеся открытыми защиты приведены в документе [CMSIS_DAP_power_reset_questions.md](CMSIS_DAP_power_reset_questions.md).

Сокращение `TGT` в именах цепей означает локальный домен target — К1986 и связанную с ним часть платы. Сокращение `LOC` используется только для локальных ветвей коммутации, например `LOC_VTREF`, и не применяется как имя шины питания.

`+3V3_DAP` и `+3V3_TGT` являются отдельными доменами с общей GND; гальваническая изоляция не предусматривается. DAP получает `+3V3_DAP` от собственного USB-C и может оставаться включённым при полностью выключенном target.

От `USB_DAP_VBUS` формируются три независимых по нагрузке тракта. Внутренний `TLV76133DCYR` постоянно питает только `+3V3_DAP`. Второй тракт проходит через `TPS2553-1`, образует защищённый выход `+5V_DAP_OUT` и одновременно питает второй `TLV76133DCYR`, формирующий `+3V3_DAP_OUT`; оба внешних выхода имеют общий целевой токовый предел около 300 мА при `RILIM=100 кОм, 1 %` и одновременно отключаются при защёлкивании защиты. Третий тракт подаёт `USB_DAP_VBUS` через отдельный силовой P-MOSFET на `+5V_DAP_USB` и далее на DAP-вход T-селектора питания локальной target. Ток К1986 не проходит через `TPS2553-1` внешних выходов, поэтому авария этого ключа не выключает локальную target.

PA1 формирует активный высоким уровнем сигнал `DAP_TARGET_PWR_EN`. Он напрямую подключается к `EN` TPS2553-1 внешних выходов DAP и через последовательный резистор 1 кОм — к gate NMOS 2N7002; gate подтянут к GND резистором 10 кОм. Отдельной прямой подтяжки 10 кОм на сети PA1/EN нет, а путь PA1 к GND составляет 11 кОм. Source 2N7002 соединяется с GND, drain — с gate силового P-MOSFET, а gate P-MOSFET подтягивается к его source на `USB_DAP_VBUS` резистором 10 кОм. При единице на PA1 включаются оба независимых силовых тракта, при нуле или high-Z они выключены. Прошивка разрешает питание только после `SET_CONFIGURATION` для USB-конфигурации с заявленным током 500 мА и выключает его при suspend, сбросе или деконфигурации USB и потере VBUS.

Защита `TLV76133DCYR` ветви `+3V3_DAP_OUT` выполняется двумя диодами Шоттки: последовательный D1 включается анодом к `+5V_DAP_OUT`, катодом к входу LDO, а D2 — анодом к `+3V3_DAP_OUT`, катодом к входу LDO. D1 блокирует продолжительное обратное питание пятивольтового выхода, D2 защищает LDO от обратного напряжения; конкретные диоды ещё не выбраны. Защита от обратного питания предусматривается только на пользовательских `+5V_DAP_OUT` и `+3V3_DAP_OUT`; подавать внешнее напряжение на остальные шины питания платы запрещено. Выходы не объединяются с XP7.1 `EXT_VTREF`: внешняя плата возвращает своё фактическое логическое питание 3,3 В на `EXT_VTREF`, в том числе при использовании `+5V_DAP_OUT` и собственного стабилизатора.

Для `TPS2553-1` приняты керамические неполярные конденсаторы: 1 мкФ X7R не менее 10 В на входе и 22 мкФ X7R не менее 10 В на выходе. Эффективная выходная ёмкость при 5 В должна быть не менее 10 мкФ. Для каждого TLV761 приняты 1 мкФ X7R на входе и 4,7 мкФ X7R на выходе; полярный символ для этих керамических конденсаторов не используется.

Локальная target питается от одного из трёх источников:

- коммутируемого P-MOSFET VBUS USB-C DAP;
- необработанного `USB_VBUS` отдельного USB-C target без дополнительного eFuse;
- внешнего VIN после отдельного преобразователя в стабильные 5 В.

Один стандартный джампер на четырёхконтактном T-образном селекторе соединяет выбранную ветвь с общим выходом `+5V_TGT`. Автоматический приоритет отсутствует. Несколько физических источников разрешено подключать одновременно, но невыбранные ветви остаются отключёнными от нагрузки. Без джампера target выключена.

От `+5V_TGT` стабилизатором `TLV76133DCYR` формируется `+3V3_TGT` для К1986, IOREF и основных контактов STMorpho. Второй `TPS2553-1` от `+5V_TGT` ограничивает суммарный ток ветви Output Power: `+5V_Out_Line` идёт на +5V, а отдельный `TLV76133DCYR` после ключа формирует `+3V3_Out_Line` для +3V3. Его `EN` при любом источнике target управляется только PB10 К1986 через штатно установленный R1004=0 Ом и сеть `TGT_OUTPUT_PWR_EN`; R27=10 кОм подтягивает `EN` к GND до настройки GPIO. Альтернативный R1104=0 Ом к `PB10_Line`/Morpho CN10.2 штатно не устанавливается; одновременно R1004 и R1104 устанавливать нельзя. `DAP_TARGET_PWR_EN` к этому ключу не подключается. Для второго ключа установлен R28=100 кОм: типовой порог около 266 мА, расчётная верхняя граница при допуске резистора 1 % около 306 мА; прошивка включает PB10 и защищённые выходы только по явной команде, без автоматического включения после инициализации. Защищённые шины также выведены на STMorpho CN7.9/CN7.16 (+3V3) и CN7.11/CN7.18 (+5V), поэтому их нагрузки учитываются вместе с выходами Arduino. CN7.26 напрямую подключён к `+5V_TGT` для высокоомного контроля питания target при выключенном ключе; это не защищённый выход и не вход внешнего питания. Прямые CN7.5/CN7.12/CN7.33 (+3V3) и CN7.6/CN7.26/CN10.8 (+5V), включая IOREF на CN7.12, служат только для высокоомного контроля напряжения; питание от них шилда или другой внешней нагрузки и внешняя подача напряжения строго запрещены. Это эксплуатационное правило, поскольку второй TPS2553-1 их не ограничивает. Питание внешней нагрузки берётся только с защищённой ветви Output Power (Arduino/Morpho); внешнее питание платы подаётся только через VIN. Контакты VIN Arduino и STMorpho относятся к одной входной сети.

При питании К1986 от USB-C DAP в бюджете VBUS зарезервировано по 100 мА на К1986 и STM32F103 с запасом относительно данных производителей и не более 300 мА суммарно на внешние нагрузки выходов DAP и защищённой ветви Output Power (Arduino/Morpho). Расчётный максимум составляет 500 мА. Два TPS2553-1 ограничивают свои ветви независимо, поэтому общий предел 300 мА является правилом эксплуатации, а не аппаратным порогом. Постоянная значительная нагрузка одновременно на оба канала не является штатным сценарием; при выборе USB-C target или VIN для питания К1986 бюджеты источников рассматриваются отдельно. Любой нештатный ток через прямые контакты Morpho также входит в общий бюджет источника и не ограничивается вторым TPS2553-1.

`FAULT` TPS2553-1 внешних выходов DAP остаётся только на локальном светодиоде и не подключается к микроконтроллерам. `FAULT` второго TPS2553-1 ветви Output Power сохраняет локальную индикацию и подтяжку R26=100 кОм к `+5V_TGT`; gate VT1=2N7002 подключён к этому узлу, source — к GND, drain подтянут R24=10 кОм к `+3V3_TGT`. Через штатно не установленный R25=1 кОм drain может подключаться к PE3 К1986 и Morpho CN10.10. При установленном R25 высокий уровень PE3 означает аварию, низкий — отсутствие активного `FAULT`, но не подтверждает наличие питания на выходе. Эта конфигурация исключает независимое использование CN10.10 шилдом. После срабатывания версии `-1` повторное включение требует переключения соответствующего `EN` либо снятия питания; автоматическое программное восстановление не предусматривается.

На листе питания между `+3V3_TGT` и GND установлен постоянный разрядный резистор; его окончательный номинал определяется после измерения прототипа. Скопированное значение 118 кОм и описание резистора обратной связи не являются утверждённым номиналом разрядного узла. Специальные буферы или ключи для гарантированного исключения подпитки через междоменные сигналы не устанавливаются. Сочетание включённого передающего и выключенного принимающего домена является принятым риском и неподдерживаемым режимом эксплуатации. На `+3V3_TGT` предусматривается отдельный индикатор питания.

Для VIN принят диапазон 8...18 В с целевым номиналом 12 В и синхронный понижающий преобразователь `LMR51410XDBVR` на 1 А с частотой 400 кГц и режимом PFM при малой нагрузке. Приняты дроссель 33 мкГн, входные конденсаторы 4,7 мкФ + 100 нФ, bootstrap-конденсатор 100 нФ, выходной конденсатор 22 мкФ и делитель обратной связи 118 кОм / 22,1 кОм; EN подключается непосредственно к VIN. Дополнительный bulk-конденсатор, внешний диод Шоттки и постоянная минимальная нагрузка не устанавливаются. Полезная нагрузка target остаётся ограниченной 300 мА. Отдельный eFuse ветви VIN не устанавливается; короткое замыкание на открытых силовых контактах и во внешней проводке считается маловероятным принятым риском, а встроенные ограничение тока и hiccup-защита преобразователя — только его аварийной самозащитой. Штатное питание платы осуществляется через USB-C DAP. Вход VIN не имеет на плате отдельной защиты от переполюсовки, длительного перенапряжения и броска входного тока; правильную полярность, стабилизированное напряжение 8...18 В, ограничение тока и необходимую входную защиту должен обеспечивать внешний источник либо shield.

## 14. VCP и UART-загрузчик

CMSIS-DAP сохраняет CDC ACM VCP. По актуальной карте выводов VCP подключается к UART2 на PD0/PD1 через альтернативные R1105/R1106. Arduino D0/D1 остаются постоянно подключёнными к UART1 на PB6/PB5 и с VCP электрически не объединяются.

### 14.1. Обычный VCP

Соединения относительно К1986ВЕ92FI:

- `DAP_VCP_TX` -> R1105 -> PD0/UART2_RXD, вывод 31;
- PD1/UART2_TXD, вывод 32 -> R1106 -> `DAP_VCP_RX`.

R1105/R1106 являются альтернативами штатным R1005/R1006, которые подключают PD0/PD1 к Morpho и ветви JTAG_B. Пары переключаются совместно:

- R1005/R1006 установлены, R1105/R1106 сняты — PD0/PD1 доступны на Morpho и JTAG_B;
- R1005/R1006 сняты, R1105/R1106 установлены — PD0/PD1 подключены к встроенному VCP.

Вторая конфигурация может использоваться как терминал работающей программы либо как физический UART-канал заводского Boot ROM в MODE=101. Она несовместима с JTAG_B и внешней опорой АЦП на PD0/PD1.

### 14.2. Внешний USB-UART для Boot ROM

Оба заводских варианта UART2 доступны для внешнего USB-UART через Morpho либо отдельную сервисную колодку. Вариант MODE=101 дополнительно доступен через встроенный VCP:

| MODE[2:0] | RXD К1986 | TXD К1986 |
|---|---|---|
| 101 | PD0/UART2_RXD, вывод 31 | PD1/UART2_TXD, вывод 32 |
| 110 | PF0/UART2_RXD, вывод 2 | PF1/UART2_TXD, вывод 3 |

Подключение выполняется перекрёстно: TX адаптера -> RXD К1986, RX адаптера <- TXD К1986, GND адаптера -> GND платы. Допустим только USB-UART с логическими уровнями 3,3 В; RS-232 и адаптер с уровнями 5 В подключать нельзя.

Отдельный электронный UART-мультиплексор не требуется: PD0/PD1 выбираются существующими парами R1005/R1105 и R1006/R1106. Для удобства можно поставить компактную колодку `GND, +3V3_TGT, PD0, PD1, PF0, PF1`; вывод `+3V3_TGT` здесь предназначен прежде всего как опорный уровень, а питание платы от адаптера должно быть явно запрещено либо отдельно защищено от обратного тока.

### 14.3. Загрузчик MODE=101 на PD0/PD1

Требуемое состояние:

```text
MODE[2:0] = 101
DBG_PORT_SEL = OFF
R1009 = установлен, AREF от +3V3_TGT
R1109 = не установлен; R1206 = не установлен (DNP)
```

PD0/PD1 одновременно имеют функции ADC0_REF+/ADC1_REF-, аналоговых входов и TMS/TCK JTAG_B. В текущей сборке внешняя опора через них не реализована: R1109 и R1206 не установлены. Перед загрузкой установить `DBG_PORT_SEL=OFF`.

Далее выбирается ровно один UART-источник:

- встроенный VCP: снять R1005/R1006 и установить R1105/R1106;
- внешний USB-UART 3,3 В на Morpho: установить R1005/R1006 и снять R1105/R1106.

После установки MODE нужно полностью выключить и снова включить Ucc target.

Постоянные UART-подтяжки и иные элементы загрузчика на PD0/PD1 ставить не следует: они ухудшат аналоговый режим. Эти выводы также не являются 5-вольт-совместимыми.

### 14.4. Загрузчик MODE=110 на PF0/PF1

Требуемое состояние:

```text
MODE[2:0] = 110
DBG_PORT_SEL = OFF
SEL_D11_SPI_PWM = PA1 либо внешняя нагрузка PF0 отключена
D13/SCK = без внешней нагрузки
```

| Вывод | UART-загрузчик | Обычная функция платы |
|---|---|---|
| PF0 | UART2_RXD | D11/MOSI на Arduino и Morpho |
| PF1 | UART2_TXD | D13/SCK на Arduino и Morpho; локальный LED не подключён |

Перед загрузкой нужно снять shield либо гарантированно исключить внешнюю нагрузку линий D11 и D13 на Arduino/Morpho. Для освобождения PF0 можно переключить `SEL_D11_SPI_PWM` с PF0 на PA1. PF1 остаётся прямой сетью D13/SCK, поэтому её внешняя нагрузка должна отсутствовать. Отдельный разъём ICSP не предусматривается. Затем подключается внешний USB-UART, устанавливается MODE=110 и выполняется полный power cycle Ucc target.

### 14.5. Согласованная архитектура

- встроенный VCP подключается только к PD0/PD1 через R1105/R1106;
- Arduino D0/D1 остаются на PB6/PB5 UART1 и не переключаются на VCP;
- MODE=101 может использовать встроенный VCP либо внешний USB-UART на Morpho, но только один источник одновременно;
- MODE=110 использует внешний USB-UART на PF0/PF1;
- MODE[2:0] задаётся независимо механическими конфигураторами;
- при UART-загрузке `DBG_PORT_SEL` устанавливается в OFF;
- после любого изменения MODE выполняется полный power cycle основного Ucc target;
- параметры протокола Boot ROM, последовательность обмена и формат загружаемого кода должны быть отдельно подтверждены по спецификации и выбранной утилите.

В инструкции пользователя следует явно привести таблицу состояний MODE и конфликтующих резисторов/селекторов. Встроенный VCP и внешний USB-UART являются только физическими UART-каналами, а не JTAG-программаторами.

### 14.6. Дополнительные функции DAP

- SWO capture включается в состав целевой прошивки: локальный источник приходит с `DBG_TDO_SWO`, внешний - с XP7.6, выбор выполняет пятая строка XP8;
- MCO от DAP MCU на OSC_IN target - через отдельный bridge и только как один из взаимоисключающих источников тактирования;
- USB Mass Storage/DAPLink - не включать без отдельного требования.

## 15. Программирование самого DAP MCU

Первичное программирование, восстановление и отладка STM32F103 выполняются внешним SWD-адаптером через установленный разъём XP5 1x5 с шагом 2,54 мм:

| Контакт XP5 | Сигнал | Назначение |
|---:|---|---|
| 1 | `+3V3_DAP` | VTref внешнего SWD-адаптера; не является входом питания платы |
| 2 | `DAP_MCU_SWDIO` | PA13/SWDIO DD2 |
| 3 | GND | Общая земля |
| 4 | `DAP_MCU_SWCLK` | PA14/SWCLK DD2 |
| 5 | `DAP_MCU_NRST` | NRST DD2 |

Префикс `DAP_MCU_` обозначает сервисные цепи программирования и отладки самого STM32F103. Он отличает их от рабочих выходов встроенного программатора `DAP_SWDIO`, `DAP_SWCLK`, `DAP_nRESET` и от общей отладочной шины target `DBG_*`.

Контакт 1 выполняется квадратной площадкой и отмечается на шелкографии. PA13 и PA14 не используются другими функциями. SWO самого DD2 на XP5 не выводится. BOOT0 и PB2/BOOT1 постоянно удерживаются в нуле отдельными резисторами 10 кОм; XP9 и переключение BOOT0 не предусматриваются. PA9/USART1_TX используется как `DAP_LOG_TX`, а PA10/USART1_RX — как `DAP_LOG_RX` внутреннего логгера DAP; эти выводы не являются интерфейсом системного UART-загрузчика.

Отдельная кнопка RESET DAP не устанавливается. Для смены прошивки сначала полностью обесточивают всю отладочную плату, отключая оба USB-C, VIN и внешние источники питания, устанавливают `DAP_ROUTE=OFF` и подключают внешний SWD-адаптер к XP5. Затем подают питание через USB-C DAP, выполняют erase/program/verify и снова полностью обесточивают плату перед отключением адаптера и восстановлением рабочей конфигурации. Обычная перезагрузка DAP также выполняется полным отключением питания платы.

XP5 относится только к DAP MCU и не соединяется с XP7, XP8, ARM 10-pin либо общей DBG-шиной локального К1986.

## 16. Предлагаемые имена сетей

| Группа | Имена |
|---|---|
| USB DAP | DP_DAP_USB, USB_DAP_DN, USB_DAP_VBUS, USB_DAP_CC1, USB_DAP_CC2, DAP_USB_PULLUP_EN_n |
| Встроенный DAP | DAP_SWCLK, DAP_SWDIO, DAP_nRESET, DAP_VTREF, nDAP_VTREF_PRESENT, DAP_SWO_RX |
| Общая шина | DBG_TCK_SWCLK, DBG_TMS_SWDIO, DBG_TDI, DBG_TDO_SWO, DBG_nTRST, DBG_nRESET, DBG_VTREF |
| JTAG_A | JA_TCK, JA_TMS, JA_TDI, JA_TDO_SWO, JA_nTRST |
| JTAG_B | JB_TCK, JB_TMS, JB_TDI, JB_TDO_SWO, JB_nTRST |
| Маршрутизация | DAP_ROUTE_EXTERNAL, DAP_ROUTE_OFF, DAP_ROUTE_TARGET, DBG_SEL_A, DBG_SEL_B, DBG_SEL_OFF |
| Питание | USB_DAP_VBUS, USB_VBUS, +5V_DAP_USB, +5V_Out_Line, +3V3_Out_Line, +5V_IN_Line, +5V_TGT, +5V_DAP_OUT, +3V3_DAP, +3V3_DAP_OUT, +3V3_TGT, BUcc, EXT_VTREF, LOC_VTREF, DBG_VTREF |
| Управление питанием | `DAP_TARGET_PWR_EN` управляет ветвями DAP; `TGT_OUTPUT_PWR_EN` от PB10 через R1004 управляет вторым TPS2553-1 ветви Output Power; R27 подтягивает его EN к GND |
| Обычный VCP / MODE=101 | DAP_VCP_TX, DAP_VCP_RX, VCP_RX_PD0, VCP_TX_PD1 |
| Логгер DAP | DAP_LOG_TX |
| UART Boot service | UART2_RX_PD0, UART2_TX_PD1, UART2_RX_PF0, UART2_TX_PF1 |
| Программирование DAP MCU | DAP_MCU_SWDIO, DAP_MCU_SWCLK, DAP_MCU_NRST, +3V3_DAP, GND |
| Индикация | DAP_COM_LED, DAP_EXT_PWR_FAULT_LED, DAP_POWER_LED, TARGET_POWER_LED; см. [CMSIS_DAP_indication.md](CMSIS_DAP_indication.md) |

Единая терминология уменьшит риск случайного соединения линий DD2 и К1986 при переносе схемы между листами.

## 17. Изменения по узлам существующей платы

| Существующий узел | Предлагаемое изменение |
|---|---|
| DD2 STM32F103 | Сохранить; проверить точную модификацию и ресурсы для CMSIS-DAP v2 + CDC/VCP + SWO + COM LED |
| XS5 mini-B | Заменить на USB-C Device с Rd 5,1 кОм, `USBLC6-2SC6` на D+/D- и номинальным VBUS 5 В без USB PD |
| XP7 | Сохранить существующий 1x6 и распиновку как выход встроенного DAP на внешнюю target; XP7.1 переименовать в `EXT_VTREF`, питание через него не передавать |
| Питание внешней target | Добавить `+5V_DAP_OUT` и `+3V3_DAP_OUT`, использовать GND соседнего `SPARE JMP`; общий токовый ключ `TPS2553-1` с `RILIM=100 кОм, 1 %`, целевым пределом около 300 мА и `TLV76133DCYR` с двухдиодной защитой от обратного тока |
| Питание К1986 от USB-C DAP | Подать `USB_DAP_VBUS` на DAP-вход T-селектора через отдельный силовой P-MOSFET; управлять его gate через NMOS 2N7002 от общего сигнала `DAP_TARGET_PWR_EN`, не пропуская ток К1986 через `TPS2553-1` внешних выходов |
| XP8 | Заменить пассивным селектором DAP_ROUTE 3x5 для SWCLK, SWDIO, nRESET, VTref и SWO |
| ARM 10-pin | Добавить отдельный стандартный 2x5 1,27 мм на общую DBG-шину для внешнего SWD/JTAG |
| SWCLK/SWDIO DD2 | Подключать к XP7 либо локальной DBG-шине только через XP8 |
| NRST target | Open-drain от DAP; окончательную схему утвердить вместе с питанием |
| XP5 UART / XP9 BOOT0 DD2 | Удалить исходный UART-разъём и XP9; XP5 выполнить как установленный сервисный SWD-разъём 1x5 с шагом 2,54 мм, BOOT0 и PB2/BOOT1 постоянно подтянуть к GND через 10 кОм |
| XP4 питание | Заменить четырёхконтактным T-образным селектором `+5V_DAP_USB / USB_VBUS / +5V_IN_Line -> +5V_TGT`; снятый джампер обеспечивает TARGET OFF |
| VIN -> +5V_IN_Line | Использовать `LMR51410XDBVR` для входа 8...18 В, номинально 12 В; установить дроссель 33 мкГн, входные 4,7 мкФ + 100 нФ, bootstrap-конденсатор 100 нФ, выходной конденсатор 22 мкФ и делитель 118 кОм / 22,1 кОм; EN подключить непосредственно к VIN; bulk-конденсатор, внешний диод и минимальную нагрузку не устанавливать |
| +3V3_TGT | Формировать от `+5V_TGT` через `TLV76133DCYR` с входным конденсатором 1 мкФ X7R и выходным 4,7 мкФ X7R; BUcc подключить напрямую |
| Выходы питания Arduino | Второй `TPS2553-1` от `+5V_TGT` ограничивает общий ток `+5V_Out_Line` и `+3V3_Out_Line`; отдельный LDO формирует 3,3 В, EN управляется PB10 К1986 через R1004 и `TGT_OUTPUT_PWR_EN`, R27=10 кОм удерживает его низким до явной команды прошивки; автоматического включения после инициализации нет. R28=100 кОм, расчётный порог требует проверки на прототипе |
| XP3/UART | Сохранить или переработать как сервисный header внешнего USB-UART; встроенный VCP подключать только к PD0/PD1 через R1105/R1106 |
| Индикация ST-Link | Заменить функциональным аналогом Nucleo COM: двухцветный красно-зелёный LED; при необходимости добавить DAP_POWER |
| MODE0-MODE2 | Убрать постоянное `000`; добавить механический конфигуратор и тестовые точки |
| PB0-PB4 | Подключать к общей шине только при выборе JTAG_A; сохранить доступ на Morpho |
| PD0-PD4 | Подключать к общей шине только при выборе JTAG_B; в режиме A не нагружать аналоговые цепи |
| PB5/PB6 UART1 | Постоянно оставить на Arduino D1/D0; к встроенному VCP не подключать |
| PD0/PD1 analog reference | Штатный R1009 оставляет AREF на `+3V3_TGT`; R1109 не устанавливать. Для будущей внешней опоры использовать R1109+R1005 и установить предусмотренный R1206 от PD1 к GND; MODE=101 использует PD0/PD1 как UART2 |
| PF0/PF1 Arduino/Morpho | Сохранить актуальную карту: PF0 освобождается переключением D11 на PA1, PF1 остаётся прямой сетью D13; для MODE=110 внешние нагрузки должны быть отключены; отдельного ICSP-разъёма нет |

## 18. Требования к разводке печатной платы

1. USB D+/D- вести парой с постоянной геометрией и непрерывной землёй.
2. `USBLC6-2SC6` каждого USB-C разместить непосредственно у разъёма, включить по проходной схеме производителя и соединить с GND коротким низкоиндуктивным путём; последовательные резисторы разместить со стороны соответствующего MCU.
3. XP8, ARM 10-pin и селектор A/B разместить ближе к точке разветвления, не создавать длинных параллельных ответвлений.
4. TCK вести наиболее аккуратно; предусмотреть рядом GND и минимизировать петлю возвратного тока.
5. Не проводить TCK и USB над разрывами опорной земли.
6. Не вести JTAG_B рядом с AREF и высокоомными аналоговыми цепями на большой длине.
7. Разместить тестовые точки на общей шине и на обеих сторонах селекторов.
8. Обеспечить визуальный доступ к положению MODE, DAP_ROUTE и DBG_PORT_SEL.
9. На шелкографии напечатать допустимые сочетания `A+001` и `B+000`.
10. Предупредить: `MODE change -> target power OFF/ON`.
11. У сервисного UART-разъёма ясно обозначить направления RX/TX относительно К1986, разместить рядом GND и маркировку `3V3 ONLY`.
12. Не добавлять на PD0/PD1 постоянные UART-подтяжки и иные элементы, нагружающие чувствительную аналоговую ветвь.
13. Разместить малоёмкостную ESD-защиту непосредственно у XP7 и ARM 10-pin.
14. Предусмотреть опциональные последовательные резисторы 22-47 Ом; SWCLK/TCK считать приоритетной линией для согласования.
15. Ответвление к ARM 10-pin сделать коротким; в позиции KEY не предусматривать электрический вывод, контактную площадку и металлический штырь, а контакт 9 подключить непосредственно к GND.
16. T-образный селектор питания разместить так, чтобы были однозначно видны положения `DAP`, `USB`, `VIN` и состояние без джампера `OFF`; установка одного стандартного джампера не должна позволять соединить два источника.
17. Силовые входы селектора и общий `+5V_TGT` трассировать на заявленный максимальный ток; не проводить импульсный узел преобразователя VIN через область USB, VTref и аналоговых цепей.
18. Разместить разрядный резистор и контрольную точку непосредственно на `+3V3_TGT`, а индикатор питания подключить к этой же целевой шине.
19. Локальные входные конденсаторы `LMR51410XDBVR` разместить непосредственно у VIN и GND, bootstrap-конденсатор — у CB и SW, а импульсный контур VIN-SW-GND сделать минимальным; цепь FB и её делитель удалить от узла SW, дросселя и других шумных проводников.

Начальную частоту OpenOCD следует ограничить, затем поднимать после измерения качества сигналов. Максимальную частоту нельзя назначать только по возможностям CMSIS-DAP MCU.

## 19. OpenOCD

Со встроенным CMSIS-DAP OpenOCD использует драйвер `cmsis-dap` и транспорт `swd`:

Минимальный каркас конфигурации:

```tcl
adapter driver cmsis-dap
transport select swd
adapter speed 1000

# Здесь должен подключаться проверенный target-файл К1986ВЕ92FI.
# source [find target/<k1986ve92fi>.cfg]
```

Для внешнего DAP через ARM 10-pin при необходимости доступен JTAG:

```tcl
adapter driver cmsis-dap
transport select jtag
adapter speed 1000
```

OpenOCD поддерживает адаптеры CMSIS-DAP и содержит Flash-драйвер Milandr, но это не гарантирует готовность конкретной board/target-конфигурации К1986ВЕ92FI. До фиксации программной части надо проверить:

- обнаружение TAP/DP;
- правильный IDCODE;
- halt/resume/step;
- управление reset;
- чтение Flash;
- erase/program/verify;
- поведение при защищённой или повреждённой Flash;
- восстановление через JTAG_A и JTAG_B;
- работу на актуальной сборке OpenOCD, используемой в проекте.

Нельзя копировать target-конфигурацию другого Milandr без проверки размеров Flash, адресов контроллера, алгоритма стирания и reset sequence.

## 20. План проверки прототипа

### 20.1. Проверка без К1986ВЕ92FI

1. Проверить все напряжения DAP и отсутствие перегрева.
2. Проверить USB enumeration CMSIS-DAP v2.
3. Проверить уникальный serial number.
4. Проверить обязательный CDC/VCP.
5. Проверить красный, зелёный, чередующийся и аварийный режимы COM LED.
6. Проверить первичную прошивку, erase/program/verify, восстановление и отладку STM32F103 внешним SWD-адаптером через XP5, включая connect-under-reset.
7. Измерить уровни всех отладочных выводов при `DAP_ROUTE=OFF`.

### 20.2. Проверка питания и изоляции

1. Проверить по отдельности питание target от USB-C DAP, USB-C target и VIN.
2. Подключить все три физических источника, проверить каждое положение T-селектора и отсутствие обратного тока в невыбранные ветви.
3. Снять джампер: `+5V_TGT` и `+3V3_TGT` должны отключиться, а параллельный резистор должен разрядить `+3V3_TGT` ниже требуемого порога за измеренное время.
4. Проверить повторное чтение MODE после полного выключения и включения target.
5. Проверить штатный power cycle target при соблюдении документированной последовательности отключения DAP_ROUTE, VCP, внешнего UART и других активных источников сигналов.
6. Измерить остаточное напряжение `+3V3_TGT` в штатной конфигурации power cycle; произвольные сочетания `DAP ON / target OFF` и `DAP OFF / target ON` не являются критериями приёмки платы.
7. Внешний DAP через ARM 10-pin, `DAP_ROUTE=OFF`: отсутствие конфликта выходов.
8. `DBG_PORT_SEL=OFF`: отсутствие электрической нагрузки на PB0-PB4 и PD0-PD4 в пределах требований.
9. `DAP_ROUTE=EXTERNAL`: локальные nRESET и VTref не должны выходить на XP7.
10. `DAP_ROUTE=TARGET`: VTref внешней платы через XP7 не должен соединяться с локальным `+3V3_TGT`.
11. Измерить напряжения, пульсации, пусковые токи и нагрев всех стабилизаторов без shield и при максимальной заявленной нагрузке.
12. Проверить перегрузку, подключение и отключение каждого разрешённого источника под нагрузкой; для незащищённой ветви VIN не проводить неконтролируемое испытание прямым коротким замыканием, поскольку этот режим принят как маловероятный риск.
13. Проверить, что прямое соединение BUcc с `+3V3_TGT` не мешает полному power cycle MODE; внешнее питание через связанный контакт Morpho запрещено.

### 20.3. Проверка JTAG_A

1. Установить MODE=001.
2. Выполнить полный power cycle target.
3. Выбрать DBG_PORT_SEL=A.
4. Установить `DAP_ROUTE=TARGET` и проверить встроенный CMSIS-DAP по SWD.
5. Установить `DAP_ROUTE=OFF` и проверить внешний DAP через ARM 10-pin по SWD и JTAG.
6. Начать с 100-500 кГц, затем 1 МГц.
7. Проверить IDCODE, halt, reset, программирование и verify.
8. Проверить, что PD0-PD7 доступны аналоговой подсистеме.

### 20.4. Проверка JTAG_B

1. Установить MODE=000.
2. Выполнить полный power cycle target.
3. Выбрать DBG_PORT_SEL=B.
4. Повторить проверку встроенного SWD и внешних SWD/JTAG.
5. Проверить отладку и Flash.
6. Подтвердить, что аналоговые AREF/A0-A2 считаются недоступными во время отладки.

### 20.5. Проверка аналоговой подсистемы

1. Установить MODE=001 и DBG_PORT_SEL=A либо OFF.
2. Подтвердить физический разрыв всех пяти джамперов ветви JTAG_B.
3. Сравнить шум, смещение и время установления ADC в положениях JTAG_A и OFF.
4. Проверить штатную внутреннюю опору АЦП; в альтернативной комплектации отдельно проверить внешнюю опору ADC0_REF+/ADC1_REF- с установленными R1005/R1109/R1206 и снятыми R1009/R1006/R1105/R1106.
5. Проверить отсутствие влияния общей DBG-шины и XP8 на PD0-PD4 при разомкнутом JTAG_B.

### 20.6. Проверка XP7, XP8 и ARM 10-pin

1. `DAP_ROUTE=EXTERNAL`: встроенный DAP -> XP7 -> внешняя target по SWD.
2. `DAP_ROUTE=TARGET`: встроенный DAP -> локальный JTAG_A/SWD и JTAG_B/SWD.
3. `DAP_ROUTE=OFF`: внешний DAP -> ARM 10-pin -> локальный JTAG_A/JTAG_B.
4. Проверить физический разрыв всех пяти цепей в OFF.
5. Проверить отсутствие питания внешней target через VTref.
6. Проверить общий токовый домен `+5V_DAP_OUT` и `+3V3_DAP_OUT`: суммарную нагрузку, падение напряжения, защёлкивание при КЗ, восстановление и отсутствие обратного тока от собственного источника внешней target.
7. Проверить, что смешанное положение джамперов обнаруживается по документации и не используется как штатное.
8. Проверить качество TCK/SWCLK с установленными вариантами последовательных резисторов.

### 20.7. Проверка VCP и UART Boot ROM

1. Проверить, что Arduino D0/D1 постоянно работают через PB6/PB5 UART1 и электрически не связаны с VCP.
2. Снять R1005/R1006, установить R1105/R1106 и проверить встроенный VCP на PD0/PD1 UART2.
3. Для MODE=101 установить DBG_PORT_SEL=OFF, оставить R1009 установленным, R1109 не установленным и PD1/REF− без соединения с GND через неустановленный R1206; выполнить полный power cycle и проверить Boot ROM через встроенный VCP.
4. Вернуть R1005/R1006, снять R1105/R1106 и повторить MODE=101 через внешний USB-UART 3,3 В на Morpho.
5. После возврата в MODE=001 проверить штатную внутреннюю опору и параметры АЦП. Внешнюю опору проверять в альтернативной комплектации с установленным R1206 и цепью R1109+R1005 по описанию в `docs/future_changes.md`.
6. Для MODE=110 установить DBG_PORT_SEL=OFF, переключить D11 с PF0 на PA1 либо снять внешнюю нагрузку PF0, освободить D13 от внешних устройств; подключить внешний USB-UART 3,3 В и выполнить полный power cycle.
7. Проверить обмен с загрузочным ПЗУ через PF0/UART2_RXD и PF1/UART2_TXD.
8. После возврата в рабочий режим проверить D11/MOSI и D13/SCK на Arduino/Morpho.
9. Проверить документированную последовательность отключения встроенного VCP и внешнего USB-UART перед выключением target; отдельно проверить защиту от ошибочного адаптера с уровнями 5 В.

### 20.8. Проверка SWO

1. В режиме JTAG_A/SWD подтвердить вывод SWO через PB0/JA_TDO.
2. В режиме JTAG_B/SWD подтвердить вывод SWO через PD4/JB_TDO.
3. Проверить захват встроенным DAP при `DAP_ROUTE=TARGET`.
4. Проверить захват от внешней target через XP7 при `DAP_ROUTE=EXTERNAL`.
5. Проверить SWO внешним отладчиком через контакт 6 ARM 10-pin при `DAP_ROUTE=OFF`.
6. Проверить ITM-сообщения, устойчивую скорость и отсутствие переполнения буфера.
7. Подтвердить, что в JTAG эта же линия работает как TDO и одновременно как SWO не используется.
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

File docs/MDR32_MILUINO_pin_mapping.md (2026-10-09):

---
custom-width: 80
---
# MDR32 MILUINO: сопоставление распиновки и карта коммутации К1986ВЕ92FI

## 1. Статус документа

Это рабочая карта коммутации сигнального листа К1986ВЕ92FI, актуализированная по текущей реализации принципиальной схемы. Документ составлен по следующим источникам:

- `ДФТВ.434519.003Э3.pdf` - существующая принципиальная схема;
- `ДФТВ.434519.003ПС.pdf` - паспорт существующей платы;
- `Проблемы схемотехники милуино_V1.docx` - перечень претензий;
- страницы 21-31 спецификации К1986ВЕ92FI - физические выводы и функции;
- UM1724 для NUCLEO-F103RB - Arduino/Morpho и SB-мосты;
- Arduino UNO R4 Minima reference manual - распиновка RA4M1 и функции Arduino-контактов.
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

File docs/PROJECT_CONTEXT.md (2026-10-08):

# Контекст проекта MDR32 MILUINO

## Назначение файла

Этот файл предназначен для передачи контекста проекта в новый чат. Он не заменяет подробные таблицы и исходные документы: перед изменением конкретного узла необходимо перечитать соответствующий раздел актуального файла в `./docs`.

## Кто и что разрабатывает
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

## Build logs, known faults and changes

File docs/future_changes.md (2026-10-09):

# Заметки для будущих изменений

Этот файл содержит согласованные идеи, реализация которых отложена. Записи здесь не означают, что изменение уже внесено в `.SchDoc`.

## Незавершённые параметры защищённой ветви Output Power

Принято управление вторым `TPS2553-1` только от К1986 при любом положении силового T-селектора. PB10, физический вывод 55, через штатно установленный R1004=0 Ом ведёт сигнал `TGT_OUTPUT_PWR_EN` на `EN` ключа. От `EN` к GND установлен R27=10 кОм: до настройки PB10 и при его высокоимпедансном состоянии выходы ветви Output Power выключены. Ветвь PB10 к `PB10_Line` и Morpho CN10.2 проходит через R1104=0 Ом, штатно не установленный. Оба резистора одновременно устанавливать нельзя: внешний сигнал CN10.2 тогда сможет воздействовать на `EN`.

`DAP_TARGET_PWR_EN` остаётся отдельной сетью управления силовым P-MOSFET ветви DAP и первым TPS2553-1 внешних выходов DAP; ко второму TPS2553-1 ветви Output Power он не подключается. На этой сети не нужен дополнительный резистор 10 кОм к GND: путь к земле уже проходит через последовательный 1 кОм и подтяжку gate NMOS 10 кОм. Силовой T-селектор выбирает только источник `+5V_TGT`; отдельная коммутация управляющего сигнала не требуется.

R28=100 кОм для второго TPS2553-1 выбран; остаётся подтвердить измерениями его диапазон ограничения и токовый бюджет защищённой ветви Output Power +5V/+3V3 вместе с STMorpho CN7.9/CN7.16 (+3V3) и CN7.11/CN7.18 (+5V) для каждого источника. При питании К1986 от USB-C DAP на оба микроконтроллера зарезервировано по 100 мА с запасом по данным производителей, а суммарный ток внешних нагрузок выходов DAP и защищённой ветви Output Power (Arduino/Morpho) не должен превышать 300 мА. Два TPS2553-1 аппаратно ограничивают только собственные ветви, поэтому общий предел 300 мА является правилом эксплуатации; постоянная значительная нагрузка обоих каналов одновременно не предполагается. Принято включать PB10 и защищённые выходы только по явной команде прошивки, без автоматического включения после инициализации; реализация команды должна учитывать выбранный источник и допустимый ток USB-C target. При сбросе К1986 выходы отключает аппаратная подтяжка R27. Прямые Morpho CN7.5/CN7.12/CN7.33 (`+3V3_TGT`) и CN7.6/CN7.26/CN10.8 (`+5V_TGT`) предназначены только для высокоомного контроля напряжения; питание от них шилда или другой внешней нагрузки и внешняя подача напряжения строго запрещены. IOREF на CN7.12 показывает уровень К1986 и при выключенных защищённых выходах, а CN7.26 позволяет контролировать `+5V_TGT`. Это правило не обеспечено аппаратным ограничением тока; любой нештатный ток с этих контактов входит в бюджет источника.

Цепь опционального контроля аварии ветви Output Power уже предусмотрена на листе питания: `FAULT` подтянут R26=100 кОм к `+5V_TGT` и управляет gate VT1=2N7002; source соединён с GND, drain подтянут R24=10 кОм к `+3V3_TGT`. R25=1 кОм от drain к PE3/CN10.10 штатно не установлен (DNP). После его установки высокий уровень PE3 означает срабатывание ключа, а внешний shield не должен управлять CN10.10. Отложены установка R25 в нужной сборке и обработка PE3 прошивкой К1986; автоматическое повторное включение после аварии не предусматривается. `FAULT` ключа DAP остаётся только на локальном светодиоде.

## Внешняя опора АЦП через AREF

В текущей сборке R1009 соединяет Arduino AREF с `+3V3_TGT`, R1109 не установлен, а R1206=0 Ом уже предусмотрен в `.SchDoc`, но штатно не установлен (DNP). Внешняя опора АЦП через AREF пока не поддерживается.

### Согласованная коммутация

Дополнительный резистор в цепи AREF+ не нужен: существующий R1109 соединяет AREF с `PD0/JB_TMS_Line`, а установленный R1005 — эту сеть с PD0/`ADC0_REF+`. Такая цепочка оставляет AREF+ связанным с Morpho CN10.34 и ветвью JTAG_B TMS. Это принято при условии, что CN10.34 не используется и JTAG_B отключён.

Для AREF− на схеме предусмотрен R1206 номиналом 0 Ом между сетью GND и PD1/`ADC1_REF−` со стороны микроконтроллера относительно R1006. AGND соединена с GND отдельно от R1206. R1206 штатно не устанавливать. Отдельный разъём и отдельный внешний источник AREF− не предусмотрены.

### Конфигурация внешней опоры

Для альтернативной комплектации с внешней опорой:

- снять R1009, R1006, R1105 и R1106;
- оставить R1005 и установить R1109 и R1206;
- отключить JTAG_B; оставить Morpho CN10.34 без подключения и внешнего управления;
- подавать на Arduino AREF допустимое внешнее опорное напряжение относительно GND и выбрать внешнюю опору АЦП К1986 (`Cfg_M_REF=1`); для штатной внутренней опоры оставить `Cfg_M_REF=0`.

В этом режиме:

```text
Arduino AREF ── R1109 ── PD0/JB_TMS_Line ── R1005 ── PD0/ADC0_REF+
GND          ── R1206 ────────────────────────────── PD1/ADC1_REF−
```

PD0/PD1 в этой конфигурации нельзя одновременно использовать для VCP UART2, JTAG_B или загрузчика UART2 MODE=101. Разомкнутый JTAG_B и пустой CN10.34 не удаляют физический отвод от цепи AREF+, поэтому при разводке и проверке прототипа следует учитывать его паразитную ёмкость и помехи. Допустимый диапазон внешней опоры и точность с такой трассировкой ещё требуют проверки.

Позиция R1206 уже соединяет в схеме вывод PD1 со стороны микроконтроллера относительно R1006 с GND; штатно резистор не устанавливается. Перед применением альтернативной комплектации проверить допустимый диапазон опоры и точность на прототипе; проверку нетлиста и ERC выполнять только по отдельному разрешению пользователя.

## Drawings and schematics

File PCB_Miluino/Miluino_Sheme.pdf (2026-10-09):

Лист | Листов 1 | 3 Инв. № подл. Подп. и дата Взам. инв. №Инв. № дубл. Подп. дата Справ. № Перв. примен.
PA7 | 56 PA6 | 57 PA5 | 58 PA4 | 59 PA3 | 60 PA2 | 61 PA1 | 62 PA0 | 63

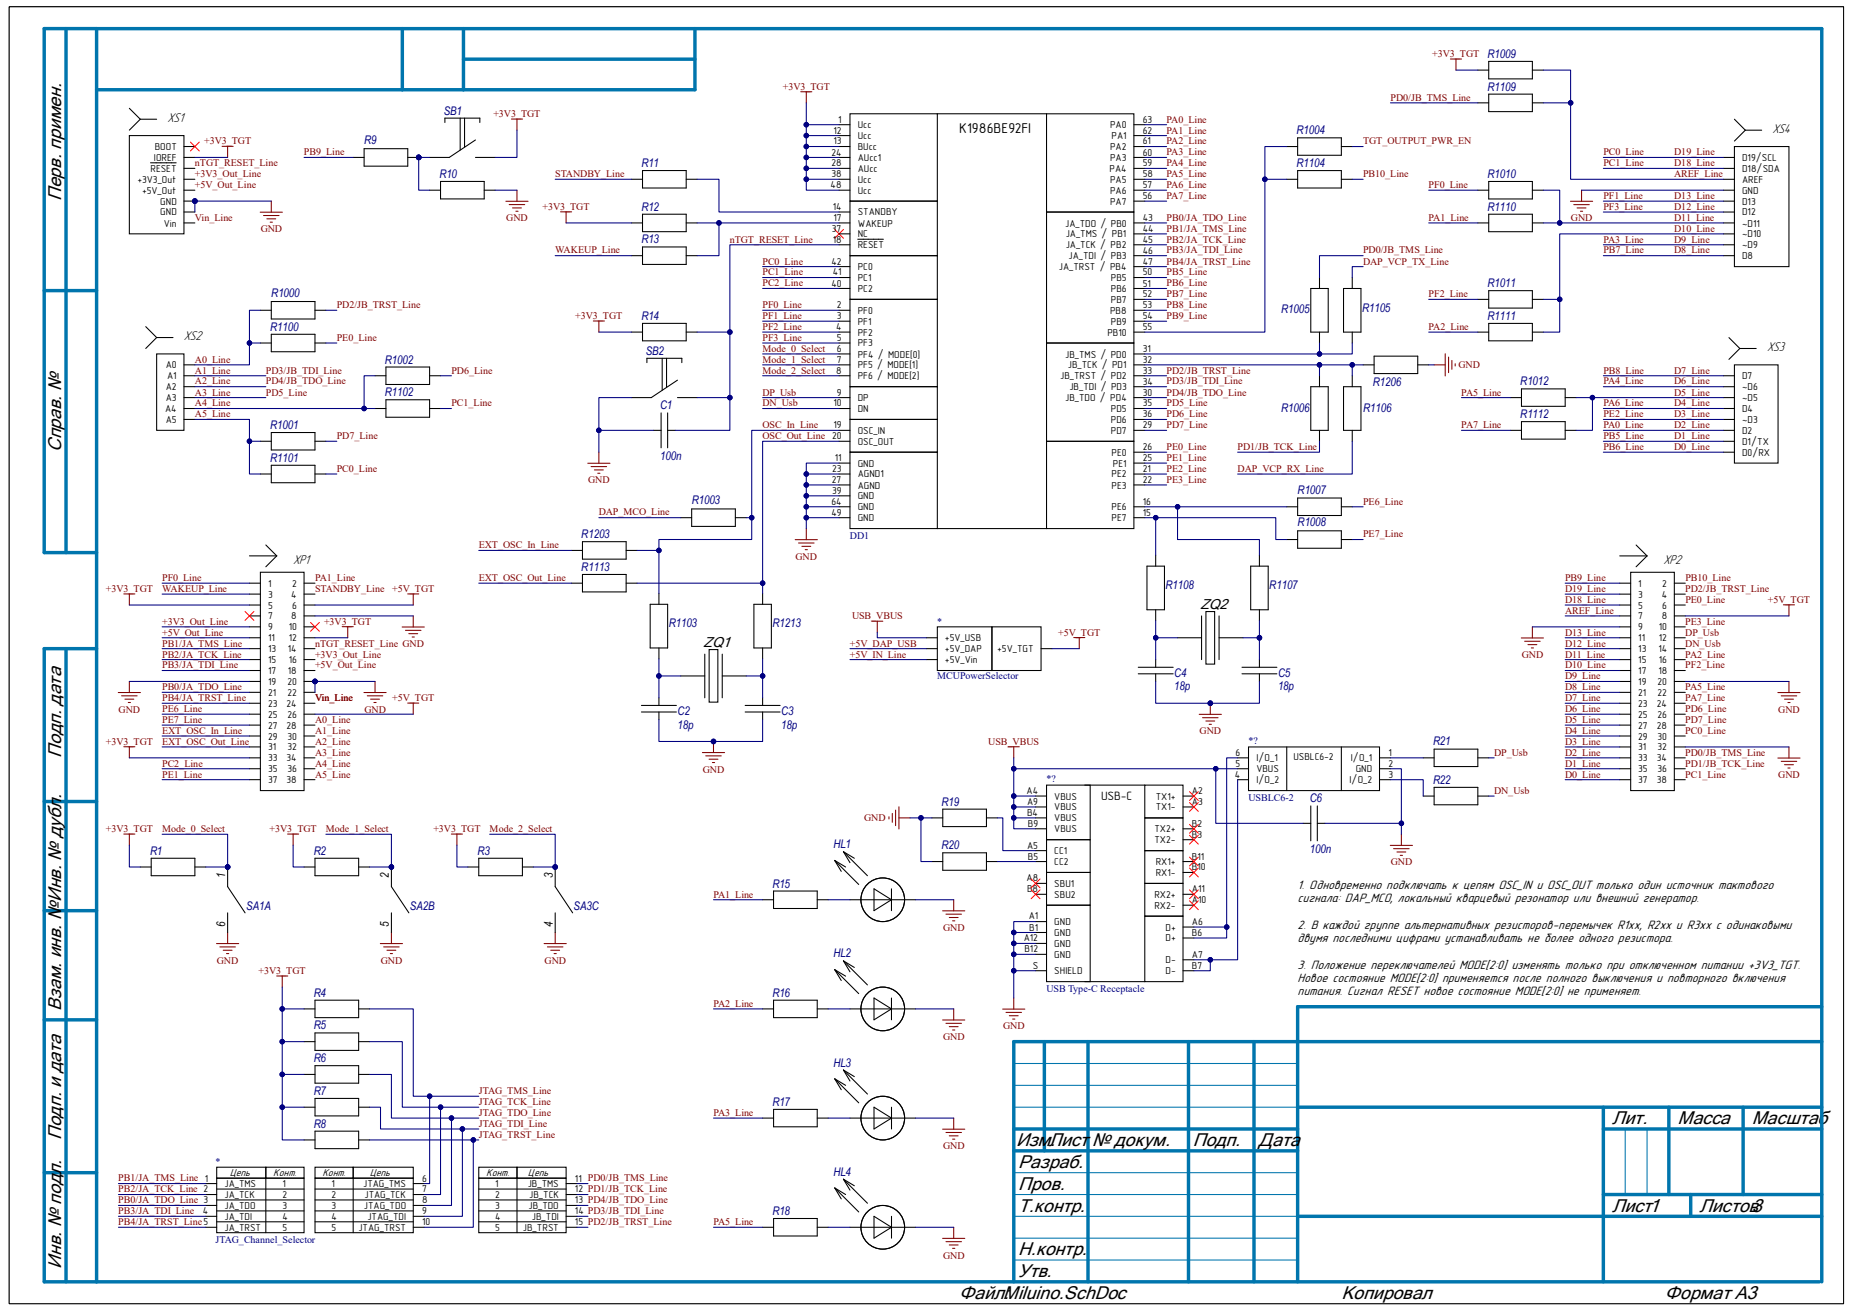
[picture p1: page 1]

1. Одновременно подключать к цепям OSC_IN и OSC_OUT только один источник тактового
сигнала: DAP_MCO, локальный кварцевый резонатор или внешний генератор.

2. В каждой группе альтернативных резисторов-перемычек R1xx, R2xx и R3xx с одинаковыми
двумя последними цифрами устанавливать не более одного резистора.

3. Положение переключателей MODE[2:0] изменять только при отключенном питании +3V3_TGT.
Новое состояние MODE[2:0] применяется после полного выключения и повторного включения
питания. Сигнал RESET новое состояние MODE[2:0] не применяет.

Изм.Лист № докум. | Подп. | Дата
Разраб.

Н.контр.
Утв.

Лист | Листов 2 | 3 Инв. № подл. Подп. и дата Взам. инв. №Инв. № дубл. Подп. дата Справ. № Перв. примен.

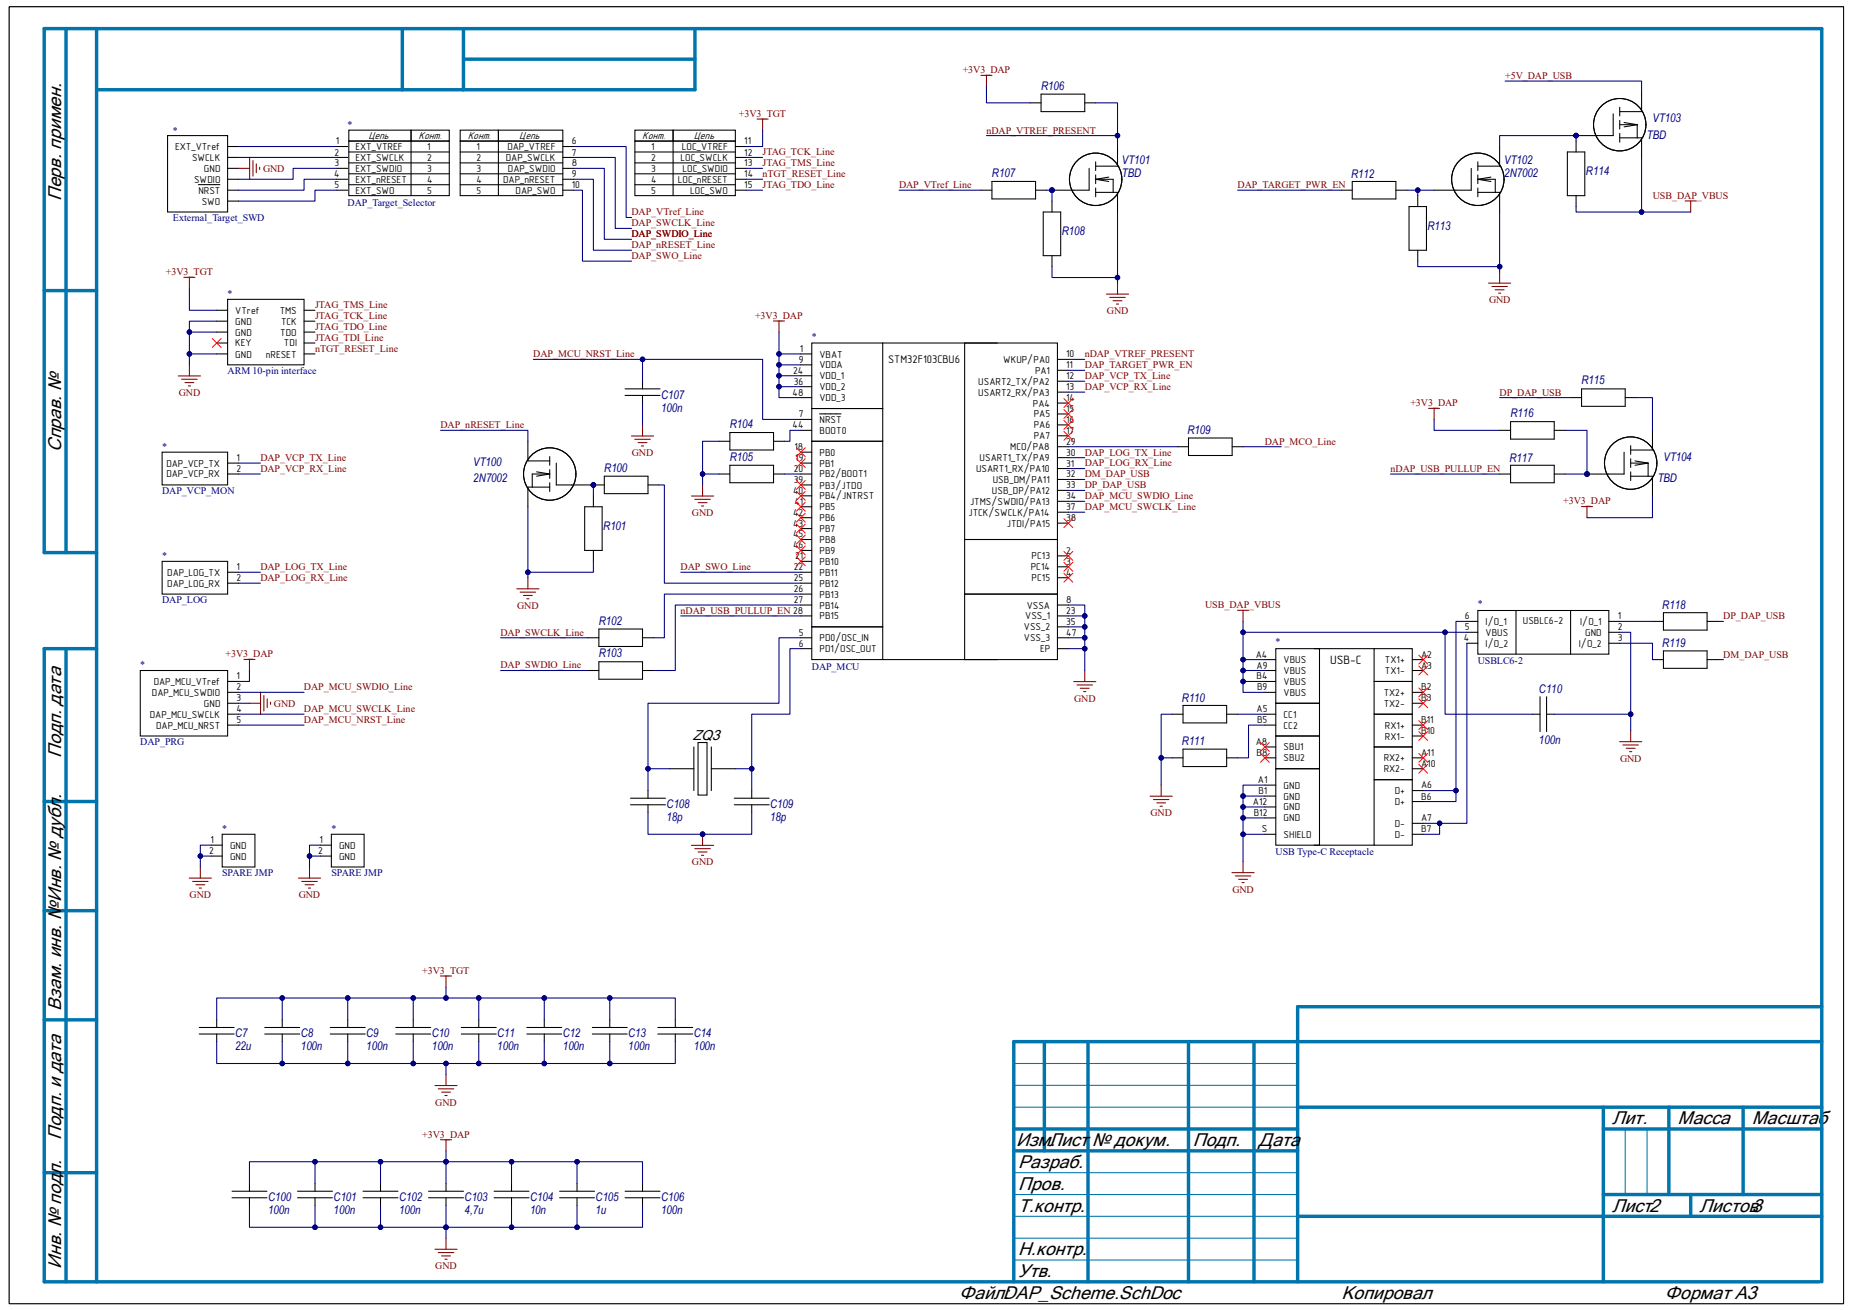
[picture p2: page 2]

Изм.Лист № докум. | Подп. | Дата
Разраб.
Пров.

Формат А4 Инв. № подл. Подп. и дата Взам. инв. №Инв. № дубл. Подп. дата Справ. № Перв. примен.

# DAP Power Sheme

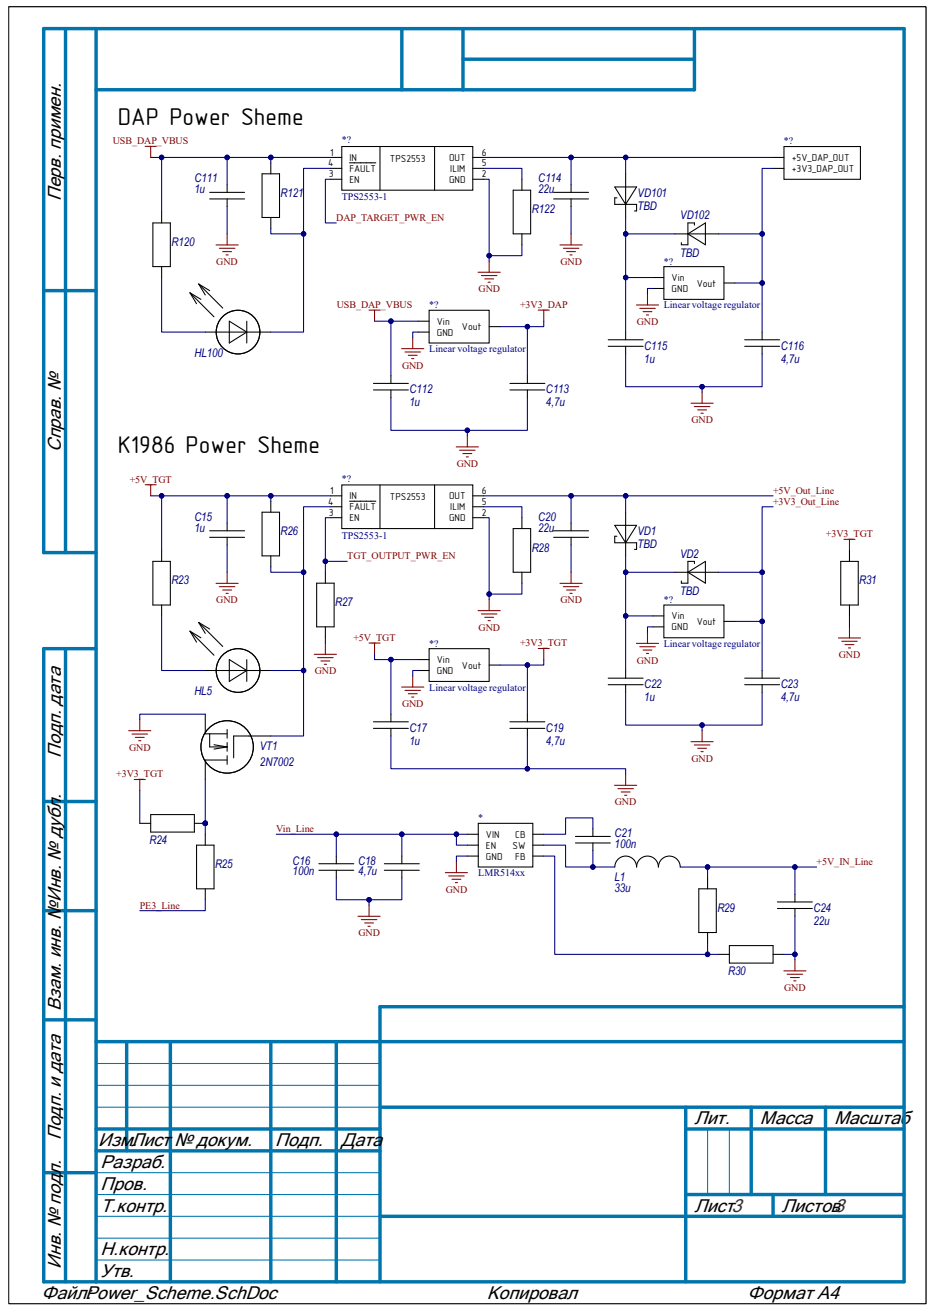
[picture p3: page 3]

Изм.Лист № докум. | | Подп. | Дата
Разраб.
Пров.

Лист | Листов 3 3

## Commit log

2026-08-07 Добавлены основные файлы и изначальный проект Miluino
    [ДФТВ.434519.001 ВПЭ — Али.xlsx, ДФТВ.434519.001 ВПЭ.xlsx, ДФТВ.434519.003 ВП (с указанием аналогов).xlsx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]
2026-08-12 Добавил камень и пины на общий .SchDoc формата А3
    [ArduinoHeaders.SchLib, JTAG_Channel_Selector.SchLib, Miluino.SchDoc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]
2026-08-13 Развёл аналоговые и цифровые пины Arduino
    [Miluino.SchDoc]
2026-08-14 Добавил разводку на пины STMorpho
    [Miluino.SchDoc, PCB_Miluino.PrjPcb]
2026-08-18 Добавил все переключаемые резисторы
    [Miluino.SchDoc]
2026-08-18 Обновил коммутацию кварцевых резонаторов и добавил нумерацию для 0 ом резисторов
    Также поменял линии для светодиодов и кнопки
    [Miluino.SchDoc]
2026-08-18 Обновлён файл MDR32_MILUINO_pin_mapping.md
2026-08-26 Добавил usb-c
    [Miluino.SchDoc, PCB_Miluino.PrjPcb, USB-C.SchLib]
2026-08-26 Добавил селектор питания MCU
    [Miluino.SchDoc, PCB_Miluino.PrjPcb, PowerSelector.PcbLib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]
2026-08-26 Добавил footprint для usb-c и mcu_power_selector
    [JTAG_Channel_Selector.PcbLib, JTAG_Channel_Selector.SchLib, PCB - CONNECTOR - USB - TE USB-C 2129691-1.PcbLib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]
2026-09-25 Начал согласовывать программатор и его реализовывать
    [ARM_10-pin_interface.PcbLib, ARM_10-pin_interface.SchLib, DAP_PRG.PcbLib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]
2026-09-29 Добавлен AGENTS и принято решение об использовании SWD для программатора
    [ARM_10-pin_interface.PcbLib, ARM_10-pin_interface.SchLib, DAP_PRG.PcbLib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]
2026-10-08 Хз чё за коммит
    [SPARE_JMP.SchLib]
2026-10-08 Начал финальную проверку
    [DAP_External_Power_Outputs.SchLib, DAP_Interface.PcbLib, DAP_Interfaces.SchLib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]
2026-10-08 Доделал схему питания отладочной платы
    [DAP_External_Power_Outputs.SchLib, DAP_Interface.PcbLib, DAP_Interfaces.SchLib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]
2026-10-08 Исправил замечания ГПТшки
    [LMR514xx.SchLib, Miluino.SchDoc, PCB_Miluino.PrjPcb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]
2026-10-08 Добавил через нейронку описание для элементов
    [DAP_Scheme.SchDoc, Miluino.SchDoc, Power_Scheme.SchDoc]
2026-10-08 Внёс опциональное подключение PD1/Aref- к GND
    [Miluino.SchDoc]
2026-10-08 Добавил TGT_OUTPUT_PWR_EN
    [Miluino.SchDoc, Power_Scheme.SchDoc]
2026-10-08 Обновил PDF схему
2026-10-08 Исправлена документация под новую схему Vout
    [Miluino.SchDoc]
2026-10-08 Подключил все выходы у XP1
    [DAP_Scheme.SchDoc, Miluino.SchDoc, Power_Scheme.SchDoc]
2026-10-09 Подключил сигнал FAULT TPS2553-1 к PE3
    [Miluino.SchDoc, Power_Scheme.SchDoc]
2026-10-09 Обновил PDF схемы
    [Miluino.SchDoc, Power_Scheme.SchDoc]
2026-10-09 Изменена нумерация элементов
    [DAP_Scheme.SchDoc, Miluino.SchDoc, Power_Scheme.SchDoc]
2026-10-09 Добавлена техническая документация
